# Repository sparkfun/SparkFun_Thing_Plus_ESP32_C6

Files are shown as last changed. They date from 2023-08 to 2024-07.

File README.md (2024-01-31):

SparkFun Thing Plus - ESP32-C6
==============================

SparkFun Thing Plus - ESP32-C6 (https://www.sparkfun.com/products/22924)

[*SparkFun Thing Plus - ESP32-C6 (DEV-22924)*](https://www.sparkfun.com/products/22924)

The SparkFun Thing Plus ESP32-C6 is a powerful wireless development board built around the ESP32-C6 WROOM-1-N16 wireless module from espressif<sup>&trade;</sup>. The ESP32-C6 is built around a single-core RISC-V processor with 16MB internal Flash memory. It supports WiFi 6, Bluetooth<sup>&reg;</sup> 5.3, Zigbee and Thread (802.12.4) wireless protocols and has a built-in PCB antenna. The ESP32-C6 has 23 multifunctional GPIO (*most* peripherals available on any GPIO), up to 7 12-bit ADC channels, up to 2 UARTs, USB Serial, one Low-Power UART, two I<sup>2</sup>C buses (one standard, one low-power), and one I<sup>2</sup>S bus.

This Thing Plus has a pair of 0.1"-spaced plated through hole (PTH) pins breaking out all of the ESP32's GPIO pins as well as connections for Reset, Boot, regulator enable, and the voltage rails (3.3V, USB, Battery), a USB-C connector, 2-pin JST connector for attaching a single-cell LiPo battery, MCP73831 battery charger, MAX17048 battery fuel gauge, 4-pin Qwiic connector, and &micro;SD card slot. The board has three LEDs for Power (Red), Battery Charge Indicator (Yellow), and STAT (RGB WS2812). The WS2812's data-in pin is tied to IO23 on the ESP32-C6.  

Repository Contents
-------------------

* **/Documents** - Datasheets, additional product information 
* **/Hardware** - Eagle design files (.brd, .sch)
* **/Production** - Production panel files (.brd)
* **/docs** - Documentation files for the Thing Plus ESP32-C6

Documentation
--------------

* **[Hookup Guide](https://docs.sparkfun.com/SparkFun_LTE_Stick_LARA_R6)** - Basic hookup guide for the SparkFun Thing Plus - ESP32-C6.

Product Versions
----------------
* [DEV-22924](https://www.sparkfun.com/products/22924) - Initial release

License Information
-------------------

This product is _**open source**_! 

Please review the LICENSE.md file for license information. 

If you have any questions or concerns on licensing, please contact technical support on our [SparkFun forums](https://forum.sparkfun.com/viewforum.php?f=152).

Distributed as-is; no warranty is given.

- Your friends at SparkFun.

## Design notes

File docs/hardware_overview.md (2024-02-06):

---
icon: material/cog
---

Let's take a closer look at the ESP32-C6 WROOM1 module and other hardware present on this Thing Plus board.

## ESP32-C6 WROOM1 Module

The ESP32-C6 WROOM1 module from espressif combines a powerful RISC-5 processor with a wireless stack compatible with most common wireless protocols.

<figure markdown>
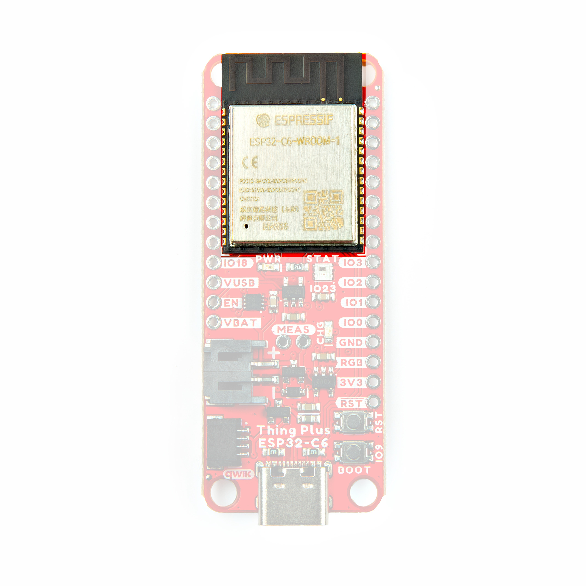
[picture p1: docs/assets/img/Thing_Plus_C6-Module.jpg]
Photo highlighting ESP32-C6 module.

</figure>

This development board uses the WROOM1 version of the C6 module which has slightly more computing power in exchange for lesser power efficiency. The ESP32-C6 is built around a 32-bit RISC-V single-core processor with an integrated wireless stack. The wireless stack is compatible with 2.4 GHz WiFi 6, Bluetooth<sup>&reg;</sup> 5.3, Zigbee and Thread (802.15.4) and uses an on-board PCB antenna. 

The module features a wide range of peripheral options including SPI, UART, LPUART, I<sup>2</sup>C, I<sup>2</sup>S, LED PWM, USB Serial/JTAG controller, ADC and more. Many of these peripherals can be mapped to any GPIO pin though some are tied to specific pins. This Thing Plus breaks out 21 pins from the module to a pair of 0.1"-spaced PTH headers.

The ESP32-C6 has 16 MB Flash memory along with 512 KB SRAM (high power)/ 16 KB SRAM (low power). The module uses pin strapping to configure boot mode parameters. The board defaults to standard mode (GPIO 9 internal pull-up, all other strapping pins floating) but it can be set to other parameters by performing the following pin strapping:

* SDIO Sampling and Driving Clock Edge - MTMS & MTDI
* Chip Boot Mode - GPIO8 & GPIO9
* ROM Code Printing to UART - GPIO8
* JTAG Signal Source - GPIO15

## Power Components

The Thing Plus ESP32-C6 includes several options for powering including USB-C, LiPo battery with on-board battery charging and monitoring circuits as well as direct power inputs.

<figure markdown>
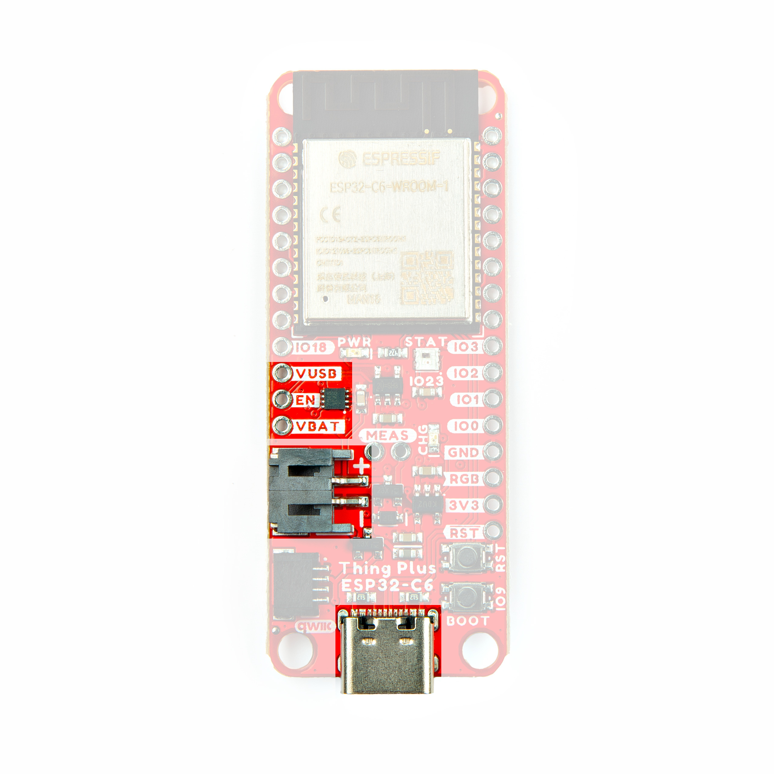
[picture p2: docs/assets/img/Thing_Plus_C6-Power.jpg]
Photo highlighting power components/pins.

</figure>

### USB-C Connector

The USB-C connector on the board acts as the primary serial interface for the ESP32-C6 module as well as a power input. It connects directly to the ESP32-C6's USB serial converter. The <b>5V</b> USB input voltage is regulated down to <b>3.3V</b> through a voltage regulator with a max current of <b>500mA@3.3V</b>.

### 2-Pin JST Connector, Battery Charger, & Fuel Gauge

The board has a 2-pin JST connector to connect a single-cell Lithium Ion (LiPo) battery for battery-powered applications. It also has an MCP73831 battery charger to charge an attached battery and a MAX17048 fuel gauge to monitor battery voltage levels over I<sup>2</sup>C. The charge rate is set to <b>214mA@3.3V</b>. The MCP73831 receives power from the V_USB line so it only is powered when <b>5V</b> is provided either over USB or the V_USB PTH pin. If applying voltage directly to the V_USB pin make sure it does not exceed <b>5.5V</b>.

## Pinout & Qwiic Connector

Next up let's take a look at the Thing Plus pinout and Qwiic connector on this board.

<figure markdown>
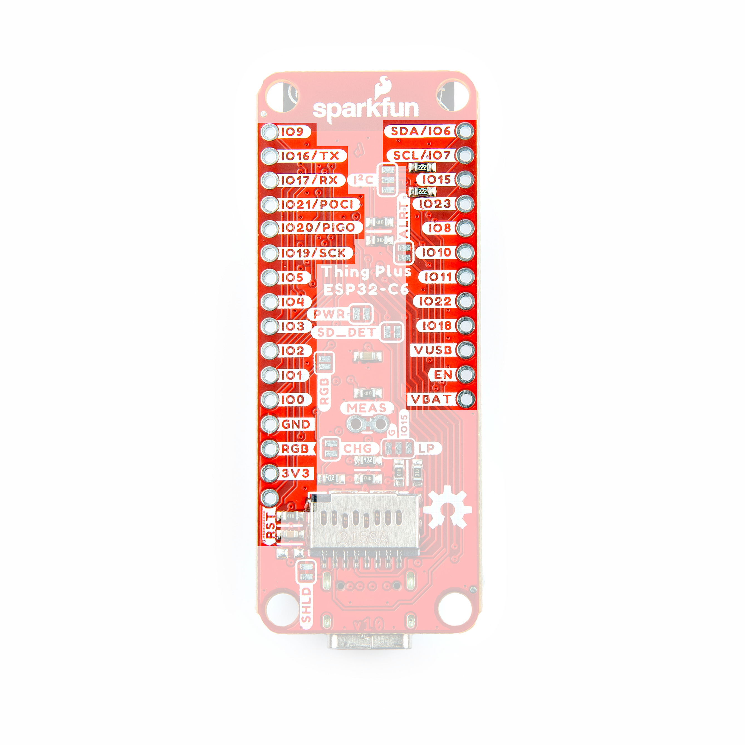
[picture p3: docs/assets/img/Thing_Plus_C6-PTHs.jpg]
Photo highlighting through-hole pinouts.

</figure>

### PTH Headers

The Thing Plus routes 23 of the ESP32-C6's GPIO pins to a pair of 0.1"-spaced headers on either side of the board. This includes all seven of the 12-bit ADC-capable pins, one UART, one I<sup>2</sup>C bus (SDA/SCL), one SPI interface (POCI/PICO/SCK), and seven GPIO pins. Some of the GPIO connect to specific functions on the board by default through solder jumpers listed below:

* IO18 - CS
* IO22 - SD Detect
* IO11 - MAX17038 Alert
* IO23 - WS2812 STAT LED Data In
* IO15 - Low Power control

### Qwiic Connector

There's a Qwiic connector on the board tied to the ESP32-C6's Low Power I<sup>2</sup>C bus (I/O pins 6 and 7) for easy integration into SparkFun's Qwiic ecosystem. The Qwiic connector provides connections for SDA, SCL, 3.3V, and Ground.

## Buttons

There are two buttons on the board labeled <b>RESET</b> and <b>BOOT</b>. The RESET button is tied to the ESP32-C6's Enable (EN) pin and resets the module when pressed. The BOOT button puts the ESP32-C6 into bootloader mode when held down during power on or reset.

<figure markdown>
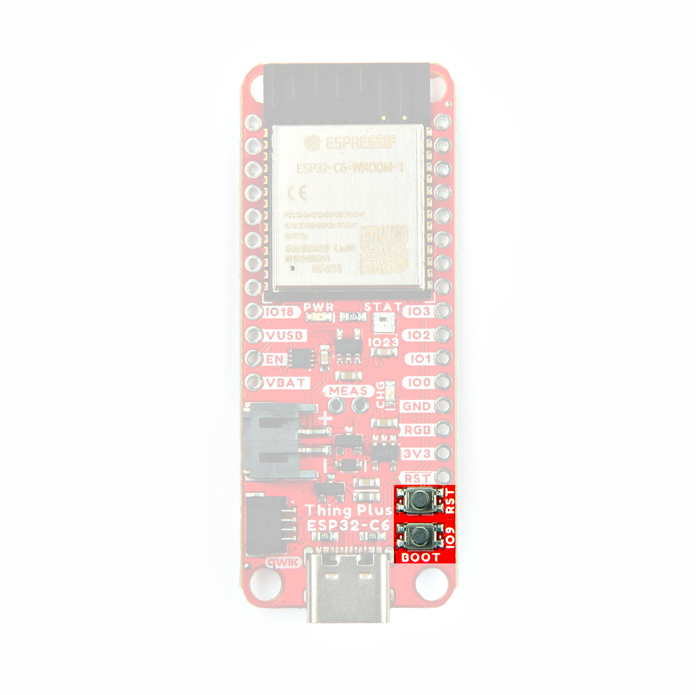
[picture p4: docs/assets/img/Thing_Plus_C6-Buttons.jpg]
Photo highlighting buttons.

</figure>

## &micro;SD Card Slot

This board also has a friction-fit &micro;SD card slot for users who need more storage space on the Thing Plus - ESP32-C6. 

<figure markdown>
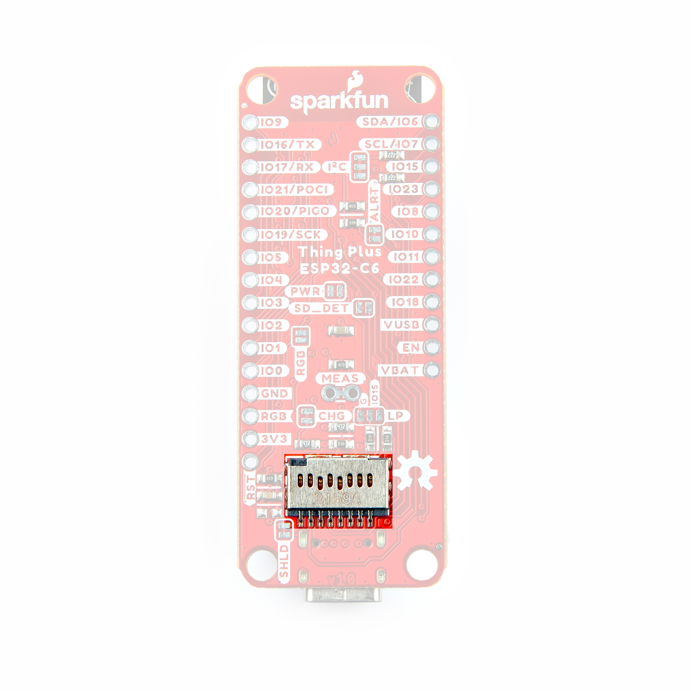
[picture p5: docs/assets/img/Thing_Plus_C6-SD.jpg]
Photo highlighting microSD card slot

</figure>

The slot connects the SD card's communication interface to the ESP32-C6's SPI interface using the following pins:

* SD Serial Data Out: IO21/POCI
* SD Serial Data In: IO20/PICO
* SD Serial Clock: IO19/SCK
* SD Chip Select: IO18/CS
* SD Detect: IO22/SD_DET

## LEDs

This Thing Plus has three LEDs labeled <b>PWR</b>, <b>CHG</b>, and <b>STAT</b>. The red Power (PWR) LED indicates whenever the <b>3.3V</b> circuit is powered. The yellow Charge (CHG) LED indicates whenever the MCP73831 is charging a connected LiPo battery. The WS2812 RGB Status (STAT) LED connects the LED's Data In signal to IO23.

<figure markdown>
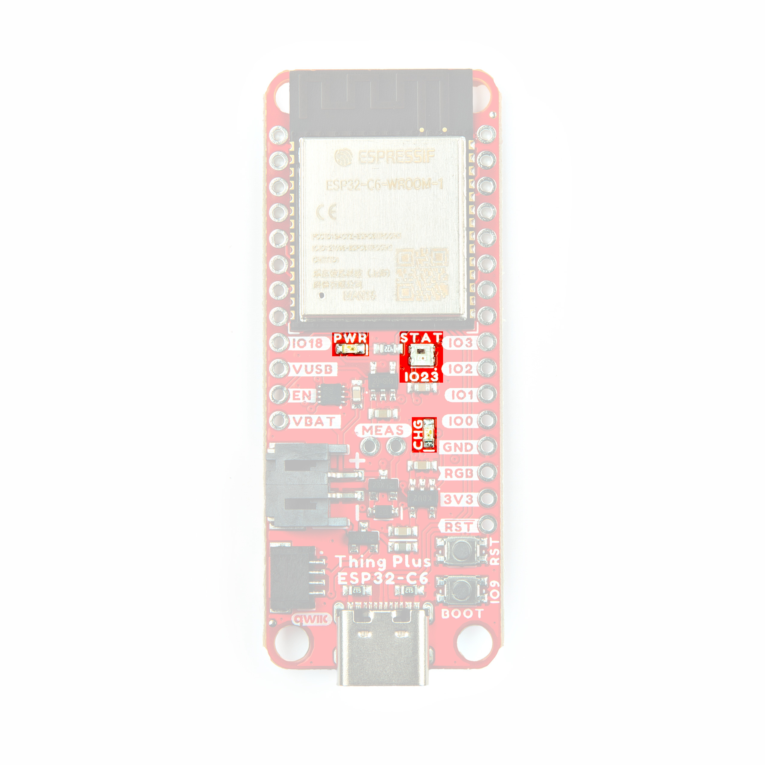
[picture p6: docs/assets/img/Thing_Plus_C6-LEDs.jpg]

</figure>

!!! note "RGB LED"
    The board definition for the Thing Plus - ESP32-C6 sets IO23 to use espressif's `RGB_BUILTIN` code support. This automatically includes the necessary code to control an RGB LED easily when calling `RGB_BUILTIN`. Unfortunately, this means the RGB PTH pin (IO23) can run into code conflicts when users attempt to use it for another purpose. If you *really* need IO23 for something other than the RGB LED, you may need to modify the board definition files in the ESP32 Arduino boards package. Modifying these files is beyond the scope of this tutorial and is not supported by SparkFun.

## Solder Jumpers

There are nine solder jumpers on the Thing Plus - ESP32-C6 labeled <b>I<sup>2</sup>C</b>, <b>ALRT</b>, <b>SD_DET</b>, <b>MEAS</b>, <b>LP</b>, <b>SHLD</b>, <b>RGB</b>, <b>CHG</b>, and <b>PWR</b>. The table below outlines the jumpers' labels, default state, function, and any notes regarding their use:

<figure markdown>
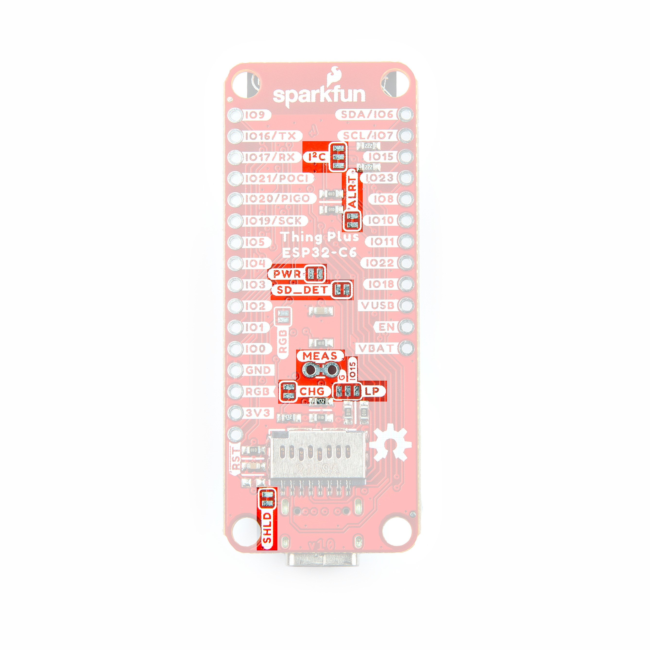
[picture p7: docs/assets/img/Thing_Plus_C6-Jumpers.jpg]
Photo highlighting solder jumpers.

</figure>

<table>
    <tr>
        <th>Label</th>
        <th>Default State</th>
        <th>Function</th>
        <th>Notes</th>
    </tr>
    <tr>
        <td>I<sup>2</sup>C</td>
        <td>CLOSED</td>
        <td>Three-way jumper pulls the SDA/SCL lines to <b>3.3V</b> through a pair of <b>2.2k&ohm;</b> resistors</td>
        <td>Open completely to disable pullups on I<sup>2</sup>C bus if needed</td>
    </tr>
    <tr>
        <td>ALRT</td>
        <td>CLOSED</td>
        <td>Ties the MAX17048's alert pin to IO11 for battery voltage monitoring</td>
        <td>Open to isolate IO11 from the MAX17048's alert pin if IO11 is needed for other uses</td>
    <tr>
        <td>SD_DET</td>
        <td>CLOSED</td>
        <td>Connects the &micro;SD card's card detection pin to IO19</td>
        <td>Open to disable &micro;SD card detection or if IO19 is needed for other uses</td>
    </tr>
    <tr>
        <td>MEAS</td>
        <td>CLOSED</td>
        <td>Completes the input voltage circuit from V_USB & V_Batt to the 3.3V regulator</td>
        <td>Open to interrupt the circuit to measure current consumed by the board with a <a href="https://learn.sparkfun.com/tutorials/how-to-use-a-multimeter#measuring-current">digital multimeter</a></td>
    </tr>
    <tr>
        <td>LP</td>
        <td>See Note</td>
        <td>Enables/disables low power control for the ESP32-C6</td>
        <td>Three-way jumper. Defaults to disabled (connects to Ground). Adjust to IO15 side to enable low power control</td>
    </tr>
    <tr>
        <td>SHLD</td>
        <td>CLOSED</td>
        <td>Ties the USB-C shield pin to the ground plane</td>
        <td>Open to isolate USB-C shield pin from the board's ground plane</td>
    </tr>
    <tr>
        <td>RGB</td>
        <td>Open</td>
        <td>Connects WS2812 data out (DO) signal to the No Connect/AREF PTH pin</td>
        <td>Open to isolate DO signal from the No Connect/AREF PTH pin to chain with other WS2812 LEDs</td>
    </tr>
    <tr>
        <td>CHG</td>
        <td>CLOSED</td>
        <td>Completes Charge LED circuit</td>
        <td>Open to disable Charge LED</td>
    </tr>
    <tr>
        <td>PWR</td>
        <td>CLOSED</td>
        <td>Completes the Power LED circuit</td>
        <td>Open to disable the Power LED</td>
    </tr>
</table>

## Board Dimensions

This board matches the Thing Plus footprint and measures 2.30" x 0.90" (58.42mm x 22.86mm) with four mounting holes that fit a [4-40 screw](https://www.sparkfun.com/products/10453) though the top two mounting holes are obstructed by the ESP32-C6 module.

<figure markdown>
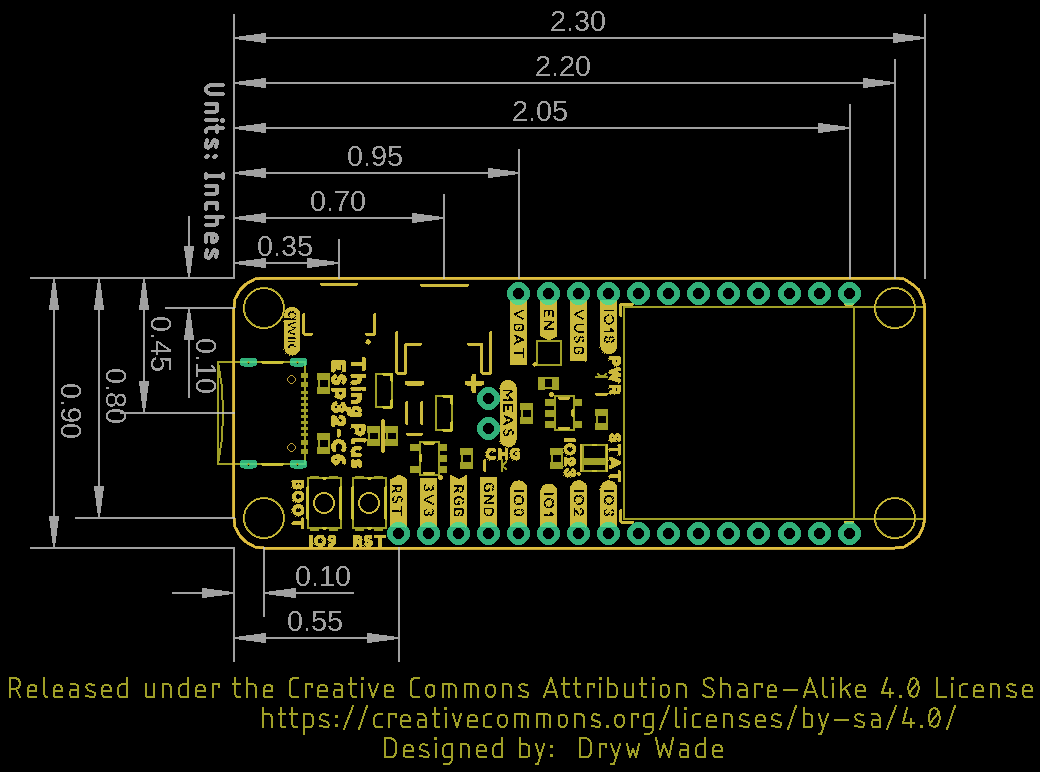
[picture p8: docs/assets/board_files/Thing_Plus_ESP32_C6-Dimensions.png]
Board dimensions.

</figure>

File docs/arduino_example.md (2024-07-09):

---
icon: simple/arduino
---

Now that we've installed the espressif boards package in Arduino, it's time to upload our first sketch to make sure everything is working properly.

## Blink RGB Example

The ESP32 core includes integrated code support for easily controlling a WS2812 LED and an example demonstrating how to cycle an RGB LED like the one found on this Thing Plus so long as the board variant defines it as `RGB_BUILTIN`. The Thing Plus ESP32-C6 does define IO23 as `RBG_BUILTIN` so this example and all other code calling for the built-in RGB LED works for this board. Open the example by navigating to **File** > **Examples** > **ESP32** > **GPIO** > **BlinkRGB** like the screenshot below shows: 

<figure markdown>
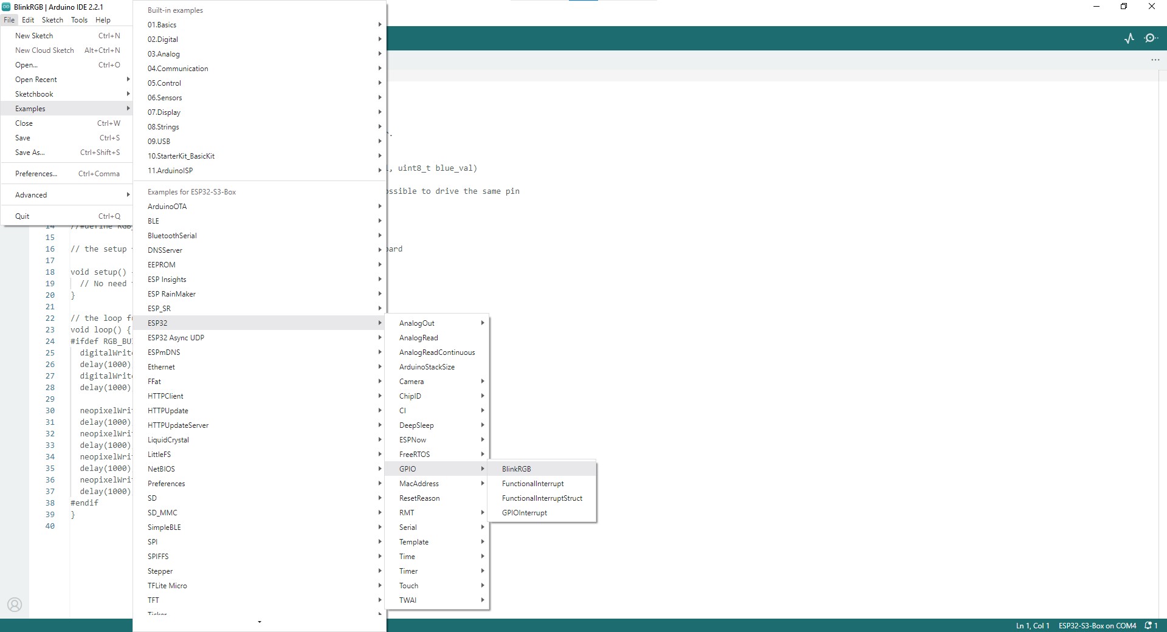
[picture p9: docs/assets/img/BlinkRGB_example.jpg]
Screenshot of selecing the Blink RGB example.

</figure>

Select the board (SparkFun Thing Plus - C6) and Port and click "Upload". After uploading you should see the STAT LED on the board turn on full white, turn off, and then cycle through red, green, and blue repeatedly.

!!! note "USB CDC On Boot Settings"

    Take note of the option labeled "USB CDC on Boot" when selecting the Board from the Tools menu. This option sets the serial outputs and defines their label for use in code. The SparkFun variants default to Enable USB CDC on boot which sets both <code>Serial</code> and <code>Serial0</code> as available serial ports. In this configuration, <code>Serial</code> corresponds to the direct USB/Serial converter on the chip (and the USB-C interface) and <code>Serial0</code> corresponds to the UART0 bus (default pins are 16 and 17).

    With either setting, <code>Serial1</code> is available and refers to the UART1 bus (default pins are 4 and 5).

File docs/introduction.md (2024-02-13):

---
icon: material/book-open-page-variant
---

<div class="grid cards desc" markdown>

-    <a href="https://www.sparkfun.com/products/22924">
    **SparkFun Thing Plus - ESP32-C6**<br>
    **SKU:** DEV-22924

    ---

    <figure markdown>
    Product Thumbnail
    </figure></a>

    <center>
    <article class="video_desc">
    <iframe src=" https://www.youtube.com/embed/UqpQe8Y62ho" title="Product Showcase: SparkFun LTE Stick - LARA-R6" frameborder="0" allow="accelerometer; autoplay; clipboard-write;encrypted-media; gyroscope; picture-in-picture" allowfullscreen></iframe>
    </article>
    </center>

-    The SparkFun Thing Plus - ESP32-C6 adds a powerful wireless development option to SparkFun's popular Thing Plus footprint. This Thing Plus board features the ESP32-C6 WROOM-1-N16 module from espressif<sup>&trade;</sup>. It includes a LiPo battery charger and fuel gauge to charge and monitor a battery connected to the on-bard 2-pin JST connector, &microSD card slot, an addressable LED and more. The board breaks out all of the ESP32-C6's 23 GPIO pins to a pair of 0.1"-spaced PTH headers on either side of the board. The board also has a USB-C connector for primary power and programming and a Qwiic connector to integrate it into SparkFun's [Qwiic ecosystem](https://www.sparkfun.com/qwiic).

    The ESP32-C6 SoC is built around a RISC-V single-core processor with 16 MB flash memory with an integrated wireless stack. The wireless stack supports 2.4 GHz WiFi 6, Bluetooth<sup>&reg;</sup> 5.3, Zigbee and Thread (802.15.4) and uses an on-board PCB antenna. The ESP32-C6 includes a wide range of peripheral options including SPI, UART, LPUART, I<sup>2</sup>C, I<sup>2</sup>S, LED PWM, USB Serial/JTAG controller, ADC and more. Many of these peripherals can be mapped to any GPIO pin though some are tied to specific pins. 

    <center>
    [Purchase from SparkFun :fontawesome-solid-cart-plus:{ .heart }](https://www.sparkfun.com/products/22924){ .md-button .md-button--primary }
    </center>

</div>

## Required Materials

To follow along with this guide you will need at least one USB-C cable to connect the Thing Plus to your computer: 

<div class="grid cards" markdown>

-   <a href="https://www.sparkfun.com/products/14743">

    <figure markdown>
    USB 3.1 Cable A to C - 3 Foot
    </figure>
    </a>
    ---
    <a href="https://www.sparkfun.com/products/14743">
    **USB 3.1 Cable A to C - 3 Foot**<br>
    CAB-14743
    </a>

-   <a href="https://www.sparkfun.com/products/15424">
    
    <figure markdown>
    Reversible USB A to C Cable - 2m
    </figure>
    </a>
    ---
    <a href="https://www.sparkfun.com/products/15424">
    **Reversible USB A to C Cable - 2m**<br>
    CAB-15424
    </a>
</div>

You may also want to get a Qwiic cable or kit to connect the Thing Plus - ESP32-C6 to other Qwiic devices:

<div class="grid cards" markdown>

-   <a href="https://www.sparkfun.com/products/17260">
    
    <figure markdown>
    Qwiic Cable - 50mm
    </figure>
    </a>
    ---
    <a href="https://www.sparkfun.com/products/17260">
    **Flexible Qwiic Cable - 50mm**<br>
    PRT-17260
    </a>

-   <a href="https://www.sparkfun.com/products/17257">
    
    <figure markdown>
    Flexible Qwiic Cable - 500mm
    </figure>
    </a>
    ---
    <a href="https://www.sparkfun.com/products/17257">
    **Flexible Qwiic Cable - 500mm**<br>
    PRT-17257
    </a>

-   <a href="https://www.sparkfun.com/products/17261">

    <figure markdown>
    Flexible Qwiic Cable - Female Jumper (4-pin)
    </figure>
    </a>
    ---
    <a href="https://www.sparkfun.com/products/17261">**Flexible Qwiic Cable - Female Jumper (4-pin)**<br>
    CAB-17261
    </a>

-   <a href="https://www.sparkfun.com/products/15081">

    <figure markdown>
    SparkFun Qwiic Cable Kit
    </figure>
    </a>
    ---
    <a href="https://www.sparkfun.com/products/15081">
    **SparkFun Qwiic Cable Kit**<br>
    PRT-15081
    </a>

</div>

## Optional Materials

The Thing Plus - ESP32-C6 includes a 2-pin JST connector and integrated charging circuit for an attached single-cell LiPo battery. Below are a few options we recommend for battery-powered applications:

<div class="grid cards" markdown align="center">

-   <a href="https://www.sparkfun.com/products/18286">

    <figure markdown>
    Lithium Ion Battery - 1250mAh (IEC62133 Certified)
    </figure>
    </a>
    ---
    <a href="https://www.sparkfun.com/products/18286">
    **Lithium Ion Battery - 1250mAh (IEC62133 Certified)**<br>
    PRT-18286
    </a>

-   <a href="https://www.sparkfun.com/products/13855">

    <figure markdown>
    Lithium Ion Battery - 2Ah
    </figure>
    </a>
    ---
    <a href="https://www.sparkfun.com/products/13855">
    **Lithium Ion Battery - 2Ah**<br>
    PRT-13855
    </a>

-   <a href="https://www.sparkfun.com/products/13851">

    <figure markdown>
    Lithium Ion Battery - 400mAh
    </figure>
    </a>
    ---
    <a href="https://www.sparkfun.com/products/13851">
    **Lithium Ion Battery - 400mAh**<br>
    PRT-13851
    </a>

-   <a href="https://www.sparkfun.com/products/13854">

    <figure markdown>
    Lithium Ion Battery - 850mAh
    </figure>
    </a>
    ---
    <a href="https://www.sparkfun.com/products/13854">
    **Lithium Ion Battery - 850mAh**<br>
    PRT-13854
    </a>
</div>

If you prefer a soldered connection or want to modify the solder jumpers on this board, you may need some of the products listed below:

<div class="grid cards" markdown align="center">

-   <a href="https://www.sparkfun.com/products/116">

    <figure markdown>
    SparkFun Qwiic Shield for Thing Plus
    </figure>
    </a>
    ---
    <a href="https://www.sparkfun.com/products/16790">
    **SparkFun Qwiic Shield for Thing Plus**<br>
    DEV-16790
    </a>

-   <a href="https://www.sparkfun.com/products/9507">
    
    <figure markdown>
    PINECIL - Smart Mini Portable Soldering Iron
    </figure>
    </a>
    ---
    <a href="https://www.sparkfun.com/products/23913">
    **PINECIL - Smart Mini Portable Soldering Iron**<br>
    TOL-23913
    </a>

-   <a href="https://www.sparkfun.com/products/9200">
    
    <figure markdown>
    Hobby Knife
    </figure>
    </a>
    ---
    <a href="https://www.sparkfun.com/products/9200">
    **Hobby Knife**<br>
    TOL-09200
    </a>

-   <a href="https://www.sparkfun.com/products/14579">

    <figure markdown>
    Chip Quik No-Clean Flux Pen - 10mL
    </figure>
    </a>
    ---
    <a href="https://www.sparkfun.com/products/14579">**Chip Quik No-Clean Flux Pen - 10mL**<br>
    CAB-14579
    </a>
</div>

## Suggested Reading

We designed this board for integration into SparkFun's Qwiic connect system.  Click on the banner below to learn more about the [SparkFun Qwiic Connect System](https://www.sparkfun.com/qwiic).

<div style="text-align: center">
<table>
  <tr>
   <td>
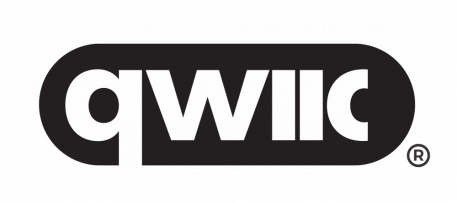
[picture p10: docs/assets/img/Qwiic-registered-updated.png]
Qwiic Connect System Click to learn more about the Qwiic Connect System!
   <div style="text-align: center"></div>
   </td>
  </tr>
  <tr>
    <td><div style="text-align: center"><i><a href="https://www.sparkfun.com/qwiic">Qwiic Connect System</a></i></div></td>
  </tr>
</table>
</div>

Before getting started with this Hookup Guide, you may want to read through the tutorials below if you are not familiar with the concepts covered in them or want a refresher. If you are using either of the Qwiic Shields linked above, we recommend reading through their respective Hookup Guides before continuing with this tutorial:

<div class="grid cards hide col-4" markdown align="center">

-   <a href="https://learn.sparkfun.com/tutorials/8">
    <figure markdown>
    Serial Communication
    </figure>
    </a>
    <a href="https://learn.sparkfun.com/tutorials/8">**Serial Communication**
    </a>

-   <a href="https://learn.sparkfun.com/tutorials/82">
    <figure markdown>
    I2C
    </figure>
    </a>
    <a href="https://learn.sparkfun.com/tutorials/82">**I2C**
    </a>

-   <a href="https://learn.sparkfun.com/tutorials/62">
    <figure markdown>
    Logic Levels
    </figure>
    </a>
    <a href="https://learn.sparkfun.com/tutorials/62">**Logic Levels**
    </a>

-   <a href="https://learn.sparkfun.com/tutorials/61">
    <figure markdown>
    Installing Arduino IDE
    </figure>
    </a>
    <a href="https://learn.sparkfun.com/tutorials/61">**Installing Arduino IDE**
    </a>

-   <a href="https://learn.sparkfun.com/tutorials/15">
    <figure markdown>
    Installing an Arduino Library
    </figure>
    </a>
    <a href="https://learn.sparkfun.com/tutorials/15">**Installing an Arduino Library**
    </a>

-   <a href="https://learn.sparkfun.com/tutorials/112">
    <figure markdown>
    Serial Terminal Basics
    </figure>
    </a>
    <a href="https://learn.sparkfun.com/tutorials/112">**Serial Terminal Basics**
    </a>

-   <a href="https://learn.sparkfun.com/tutorials/1107">
    <figure markdown>
    SparkFun Qwiic Shield for Thing Plus Hookup Guide
    </figure>
    </a>
    <a href="https://learn.sparkfun.com/tutorials/1107">**SparkFun Qwiic Shield for Thing Plus Hookup Guide**
    </a>

-   <a href="https://learn.sparkfun.com/tutorials/664">
    <figure markdown>
    How to Work with Jumper Pads and PCB Traces
    </figure>
    </a>
    <a href="https://learn.sparkfun.com/tutorials/664">**How to Work with Jumper Pads and PCB Traces**
    </a>
</div>

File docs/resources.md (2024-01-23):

For more information on the Thing Plus ESP32-C6, check out the resources below:

* [Schematic](./assets/board_files/Thing_Plus_ESP32_C6.pdf)
* [Eagle Files](./assets/board_files/Thing_Plus_ESP32_C6.zip)
* [Board Dimensions](./assets/board_files/Thing_Plus_ESP32_C6-Dimensions.png)
* [Datasheet](./assets/component_documentation/ESP32-C6-WROOM-1-Datasheet.pdf) (ESP32-C6 WROOM-1)
* [Technical Reference Manual](./assets/component_documentation/ESP32-C6_Technical_Reference_Manual.pdf)
* [GitHub Repository](https://github.com/sparkfun/SparkFun_Thing_Plus_ESP32_C6)
* [Thing Plus Info Page](https://www.sparkfun.com/thing_plus)
* [Qwiic Info Page](https://www.sparkfun.com/qwiic)

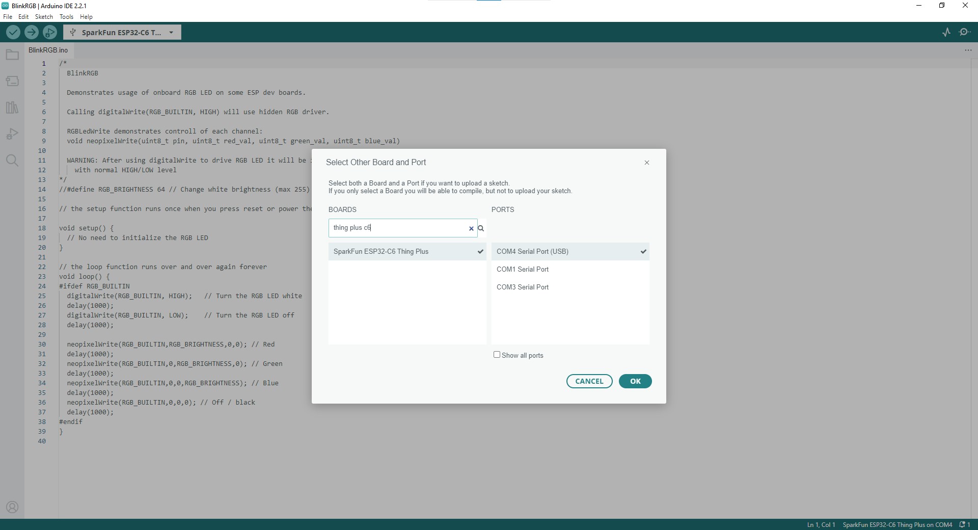
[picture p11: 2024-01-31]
docs/assets/img/Board_Selection.jpg

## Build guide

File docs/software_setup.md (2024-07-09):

---
icon: simple/arduino
---

!!! attention
	If this is your first time using Arduino, please read through our tutorial on [installing the Arduino IDE](https://learn.sparkfun.com/tutorials/installing-arduino-ide). If you have not installed an Arduino library before, we recommend you check out our [installation guide](https://learn.sparkfun.com/tutorials/installing-an-arduino-library).

With the ESP32-C6 Thing Plus connected to our computer, it's time to set up the boards package in Arduino.

## Installing espressif Arduino Boards
    
To install the ESP32 boards package, open the Preferences menu by navigating to <b>File</b> > <b>Preferences</b>. Look at the bottom of the Preferences menu for "Additional boards manager URLS" and then copy this JSON link into that field:

<code>
    https://espressif.github.io/arduino-esp32/package_esp32_dev_index.json
</code>

Click "Ok" and then open the *Boards Manager* tool, search for "espressif ESP32" and install the latest release. This install process may take some time so feel free to step away while it downloads and installs.

<figure markdown>
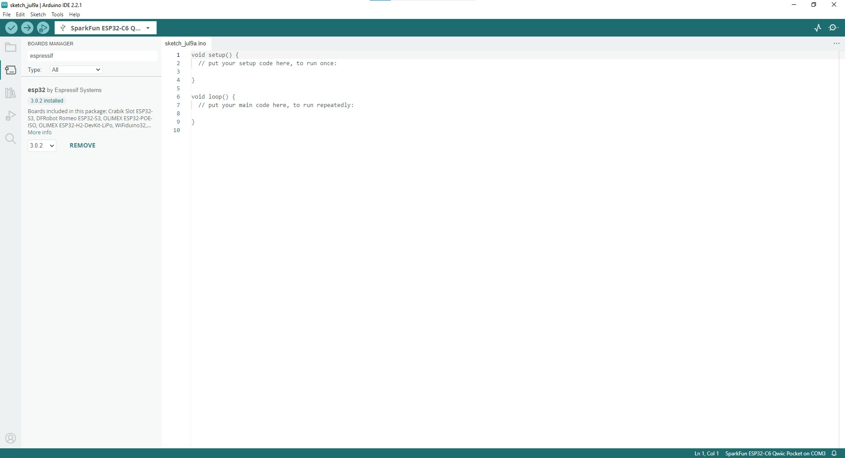
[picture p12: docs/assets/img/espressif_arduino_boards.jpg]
ESP32 Boards manager install.

</figure>

## espressif IDF

Users who prefer to use espressif's development toolkit, espressif IDF, can get started by following their instructions [here](https://www.espressif.com/en/products/sdks/esp-idf) and  ESP32-C6 specific documentation [here](https://docs.espressif.com/projects/esp-idf/en/stable/esp32c6/index.html).

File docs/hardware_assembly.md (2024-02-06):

---
icon: material/cog
---

Now that we're familiar with the hardware on this Thing Plus board, it's time to connect it to our computer or battery power.

## Basic USB Assembly

Basic assembly of the Thing Plus ESP32-C only requires a USB-C cable connecting the board to a computer. Just plug the cable into the USB-C connector like the photo below shows and you should see the RGB LED cycling through rainbow colors with the pre-loaded test code. From here, we can move on to installing the espressif boards package in Arduino and uploading code.

<figure markdown>
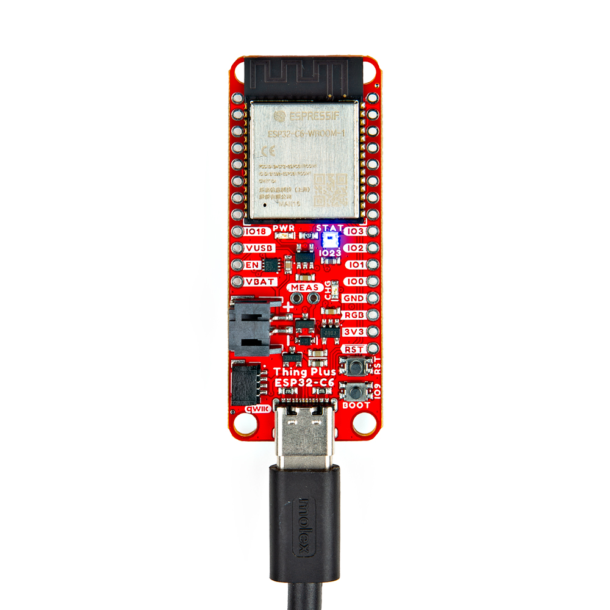
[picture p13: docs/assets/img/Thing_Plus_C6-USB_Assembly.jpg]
Photo of simple USB assembly.
    
</figure>

!!! note
    Your computer may not recognize the board as a known USB device if you have not installed the espressif boards package in Arduino and/or installed the espressif IDF.

## Battery Assembly

If you prefer a battery-powered application, plug a single-cell LiPo battery into the 2-pin JST connector on the underside of the board like the photo below. Remember, the MCP73831 only charges the battery when V_USB has voltage present either from the USB-C connector or through the V_USB PTH pin.

<figure markdown>
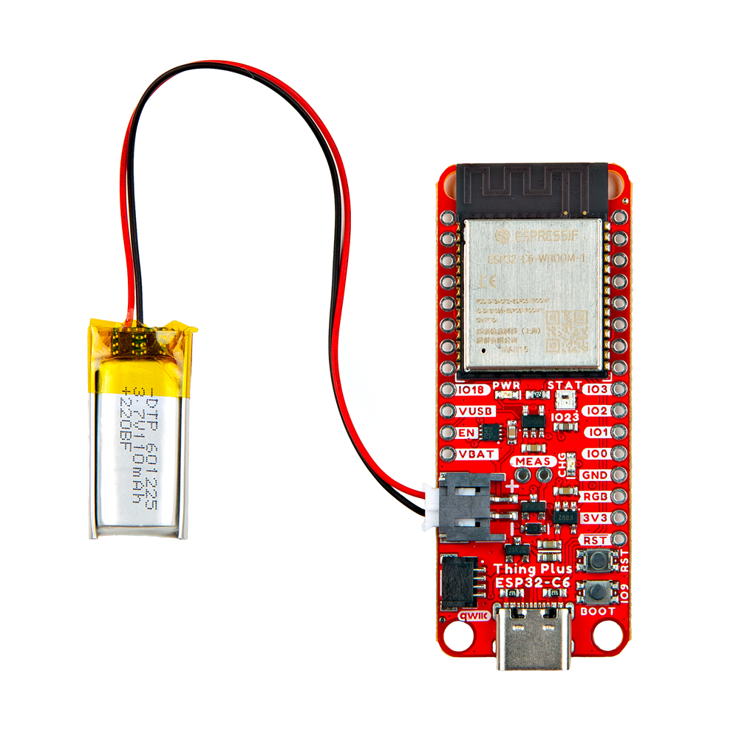
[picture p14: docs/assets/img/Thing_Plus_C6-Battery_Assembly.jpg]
Photo of battery assembly.

</figure>

For tips on the proper use of a LiPo battery and the 2-pin JST connector, please read through our [Single Cell LiPo Battery Care](https://learn.sparkfun.com/tutorials/single-cell-lipo-battery-care) tutorial.

## Soldered Assembly

Those who prefer a traditional soldered assembly should solder wires or header pins to the PTH header on the side of the board. If you're not familiar with through-hole soldering or would like a refresher, take a look at our Through-Hole Soldering Tutorial:

<div class="grid cards" markdown align="center">

-   <a href="https://learn.sparkfun.com/tutorials/5">
    <figure markdown>
    How to Solder: Through-Hole Soldering
    </figure>
    </a>
    <a href="https://learn.sparkfun.com/tutorials/5">**How to Solder: Through-Hole Soldering**
    </a>

</div>

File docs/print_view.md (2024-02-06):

---
hide:
  - navigation
  - toc
icon: fontawesome/solid/scroll
---

# Introduction
--8<-- "./docs/introduction.md:5"

# Hardware Overview
--8<-- "./docs/hardware_overview.md:5"

# Hardware Assembly
--8<-- "./docs/hardware_assembly.md:5"

## Software Setup
--8<-- "./docs/software_setup.md:5"

## Arduino Examples
--8<-- "./docs/arduino_example.md"

# Troubleshooting Tips
--8<-- "./docs/troubleshooting.md:5"

# Resources:
--8<-- "./docs/resources.md"

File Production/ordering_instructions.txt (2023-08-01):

panel size, 107x201mm
PCB thickness, 1.6mm
number of layers, 4
controlled impedance, JLC7628
soldermask color, Red
silkscreen color, White
oz copper, 1oz
finish, HASL lead free
stencils, top+bottom
pcs per panel, 12
min trace width, 0.1778mm / 0.0070in
min drill size, 0.3048mm / 0.0120in
filename to layer stackup 1/2/3/4: GTL, GL2, GL3, GBL

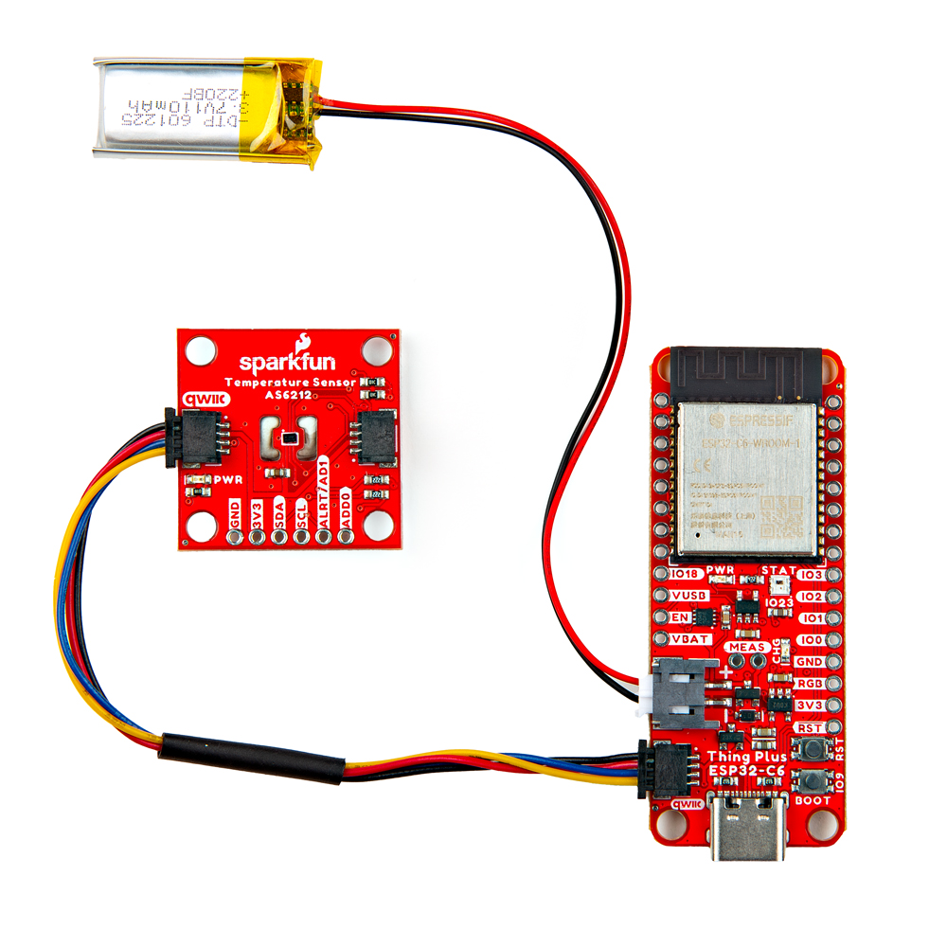
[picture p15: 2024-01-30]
docs/assets/img/Thing_Plus_C6-Qwiic_Batt_Assembly.jpg

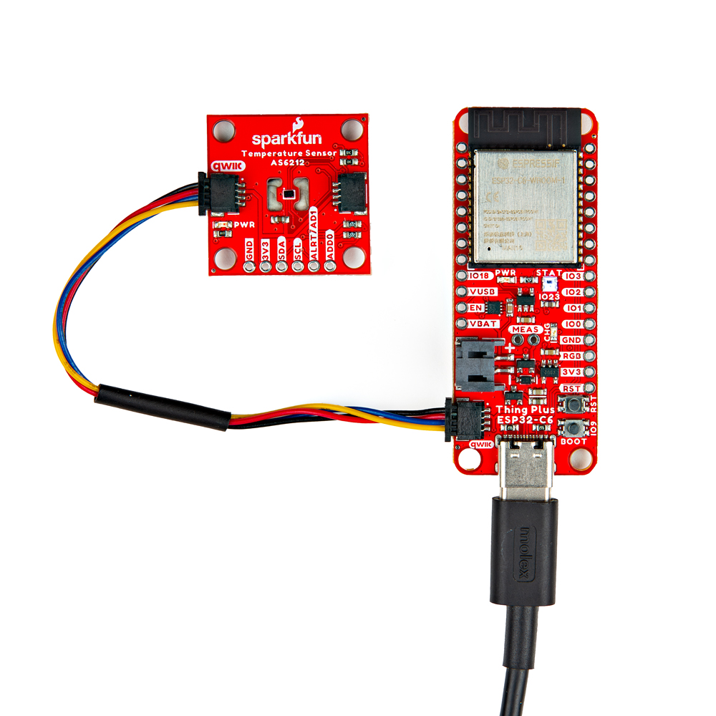
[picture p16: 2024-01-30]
docs/assets/img/Thing_Plus_C6-Qwiic_USB_Assembly.jpg

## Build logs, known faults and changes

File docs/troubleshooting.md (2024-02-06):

## USB CDC on Boot Settings

Take note of the option labeled "USB CDC on Boot" when selecting the Board from the Tools menu. This option sets the serial outputs and defines their label for use in code. The SparkFun variants default to Enable USB CDC on boot which sets both <code>Serial</code> and <code>Serial0</code> as available serial ports. In this configuration, <code>Serial</code> corresponds to the direct USB/Serial converter on the chip (and the USB-C interface) and <code>Serial0</code> corresponds to the UART0 bus (default pins are 16 and 17).

With either setting, <code>Serial1</code> is available and refers to the UART1 bus (default pins are 4 and 5).

## RGB LED Pin

The board definition for the Thing Plus - ESP32-C6 sets IO23 to use espressif's `RGB_BUILTIN` code support. This automatically includes the necessary code to control an RGB LED easily when calling `RGB_BUILTIN`. Unfortunately, this means the RGB PTH pin (IO23) can run into code conflicts when users attempt to use it for another purpose. If you *really* need IO23 for something other than the RGB LED, you may need to modify the board definition files in the ESP32 Arduino boards package. Modifying these files is beyond the scope of this tutorial and is not supported by SparkFun.

## General Troubleshooting

!!! warning "Need Help?"
    If you need technical assistance or more information on a product that is not working as you expected, we recommend heading on over to the [SparkFun Technical Assistance](https://www.sparkfun.com/technical_assistanc) page for some initial troubleshooting.

    <center>
    [SparkFun Technical Assistance Page](https://www.sparkfun.com/technical_assistance){ .md-button .md-button--primary }
    </center>
    
    If you can't find what you need there, the [SparkFun Forums](https://forum.sparkfun.com/index.php) is a great place to search product forums and ask questions.
    
    !!! info "Account Registration Required"
        If this is your first visit to our forum, you'll need to create a [Forum Account](https://forum.sparkfun.com/ucp.php?mode=register) to post questions.

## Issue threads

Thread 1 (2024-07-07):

Update docs to reflect Thing Plus ESP32-C6 board library availability

faludi, 2024-07-07:
The documentation in docs/software_setup.md should be updated to reflect that the Thing Plus ESP32-C6 is now included in the official ESP32 boards package, and that using the ESP32C6 Dev Module board definition is no longer required.

SFEMark, 2024-07-09:
The software_setup.md file and the relevant screenshots have been updated to the v3.x release of the ESP32 boards package.

Closed 2024-07-09.

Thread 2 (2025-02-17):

Fuel Gauge reporting voltage when no battery is connected

Topo-png, 2025-02-17:
I'm trying to troubleshoot a potential hardware issue.

When I power the ESP32-C6 Things Plus board via a usb cable (no battery connected- the Fuel Gauge reports back 4.0 +/- a 0.1V and provides a SOC.  Code is below

Based on the schematic it looks like the fuel gauge should only receive power when the battery is connected. When the battery and USB cable are connected, the SOC & Voltage do not change.

Could this be a potential mosfet failure, or is there another explanation?

using the following code

```
#include <Wire.h>
#include <SparkFun_MAX1704x_Fuel_Gauge_Arduino_Library.h>

SFE_MAX1704X lipo(MAX1704X_MAX17048);

void setup() {
  Serial.begin(115200);
  Wire.begin();

  if (!lipo.begin()) {
    Serial.println("MAX17048 not detected");
    while (1)
      ;
  }
  lipo.quickStart();
  lipo.setThreshold(20);
  digitalWrite(RGB_BUILTIN, HIGH);  // Turn the RGB LED white
}

void loop() {

  Serial.println(lipo.getVoltage());
  Serial.println(lipo.getSOC());
  delay(1000);
}
```

sfe-SparkFro, 2025-02-17:
Hi there,

This is expected behavior due to the presence of the battery charger. IIRC the charger IC attempts to detect a battery by supplying a small amount of current and watching how the voltage changes; if no battery is connected, the voltage rises quickly (to ~4V), and the charger determines no battery is connected, so it waits for a little while and repeats. The fuel gauge IC measures this voltage and determines a that battery is connected (and estimates a SoC). despite no battery actually being connected.

Sounds like there's no defect with your board, this behavior is just a side effect of having a charger on the board. Hope this helps!

Topo-png, 2025-02-17:
Thanks for the quick response. That makes sense.

Closed 2025-02-17.

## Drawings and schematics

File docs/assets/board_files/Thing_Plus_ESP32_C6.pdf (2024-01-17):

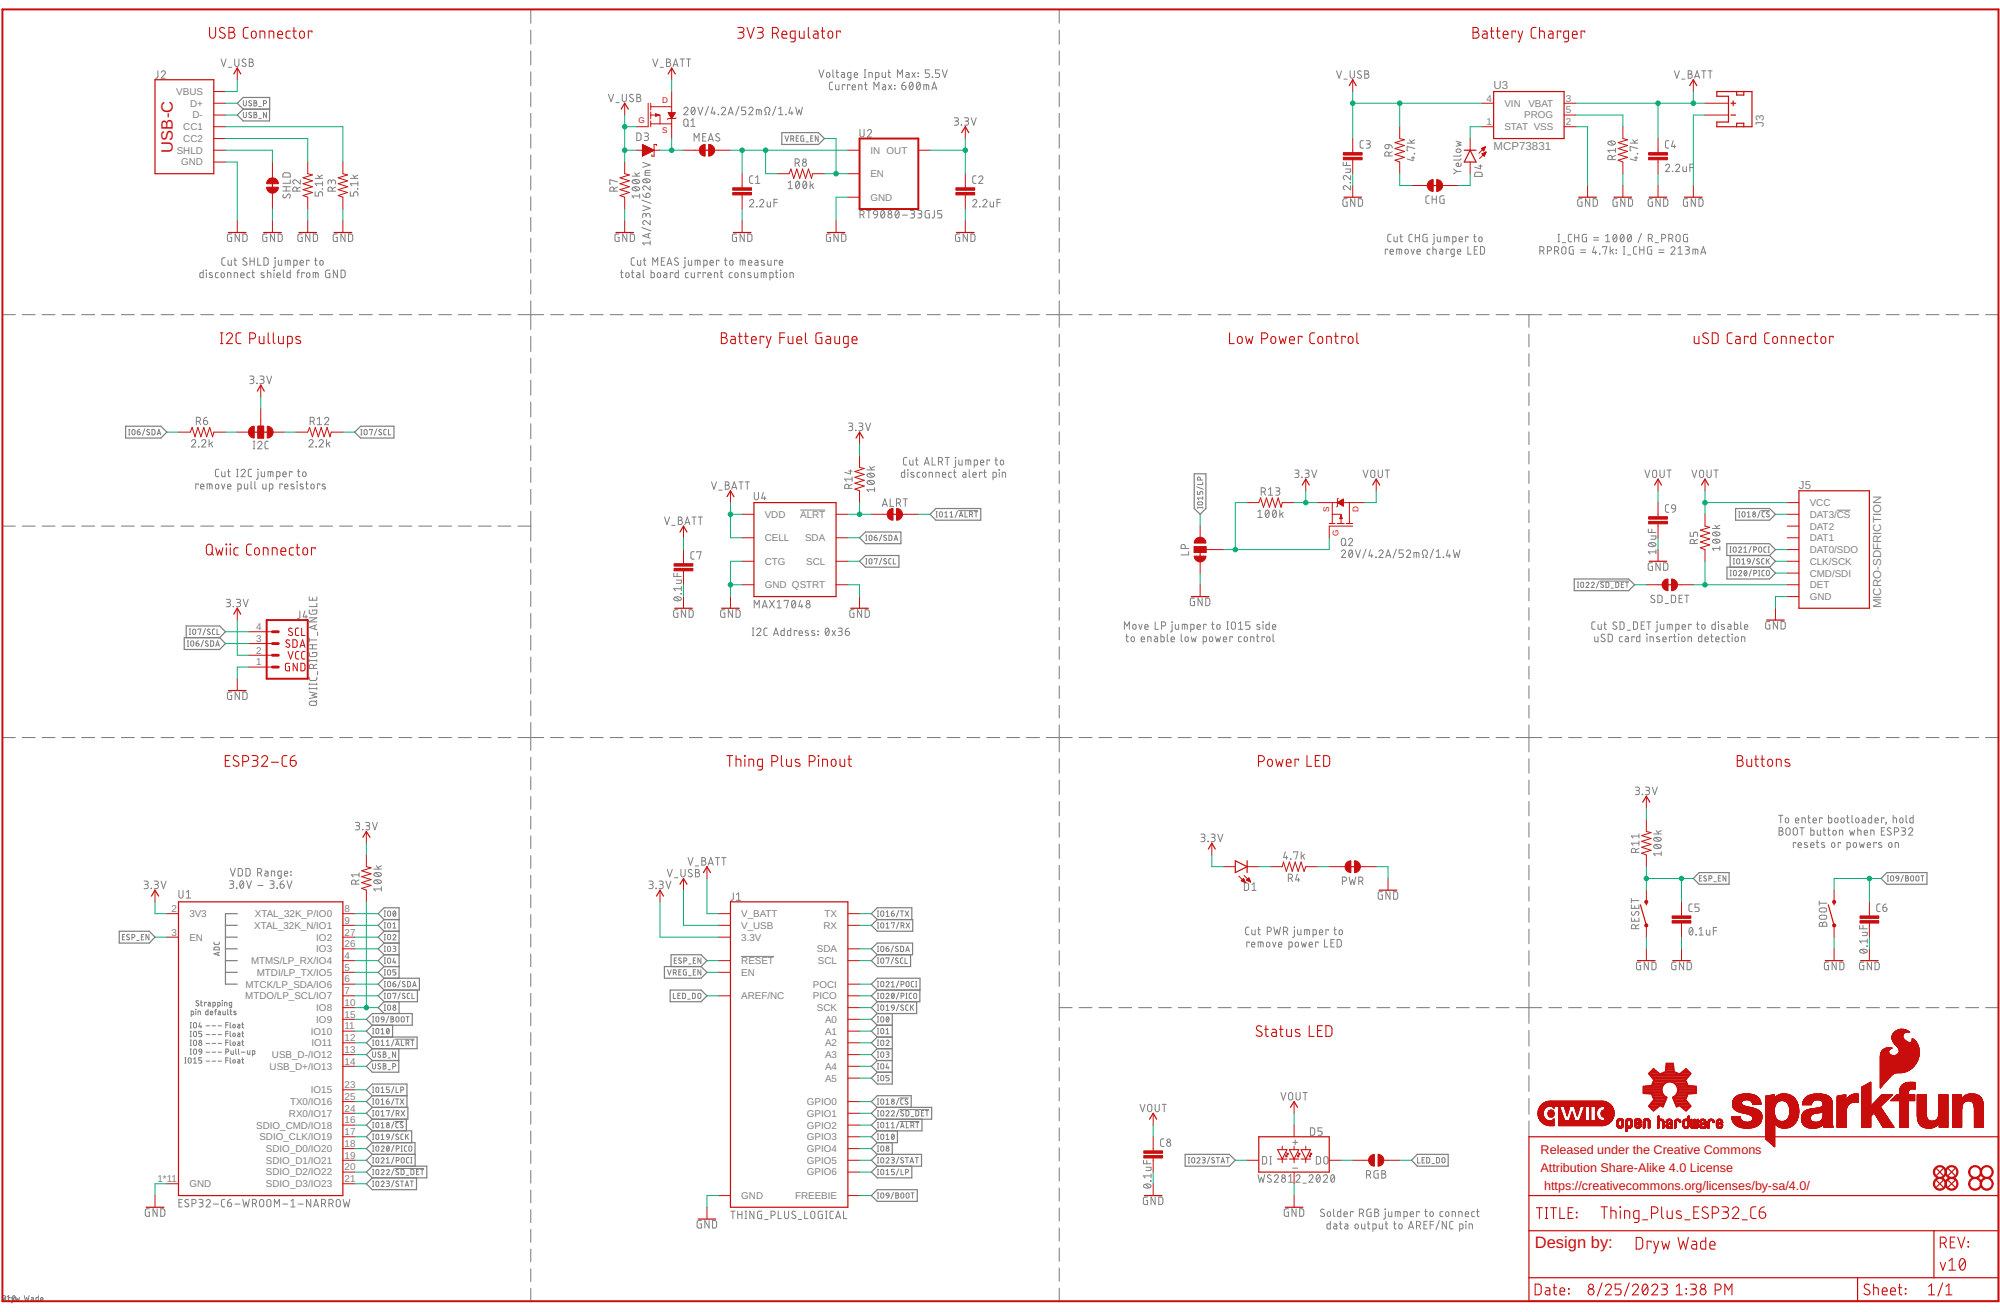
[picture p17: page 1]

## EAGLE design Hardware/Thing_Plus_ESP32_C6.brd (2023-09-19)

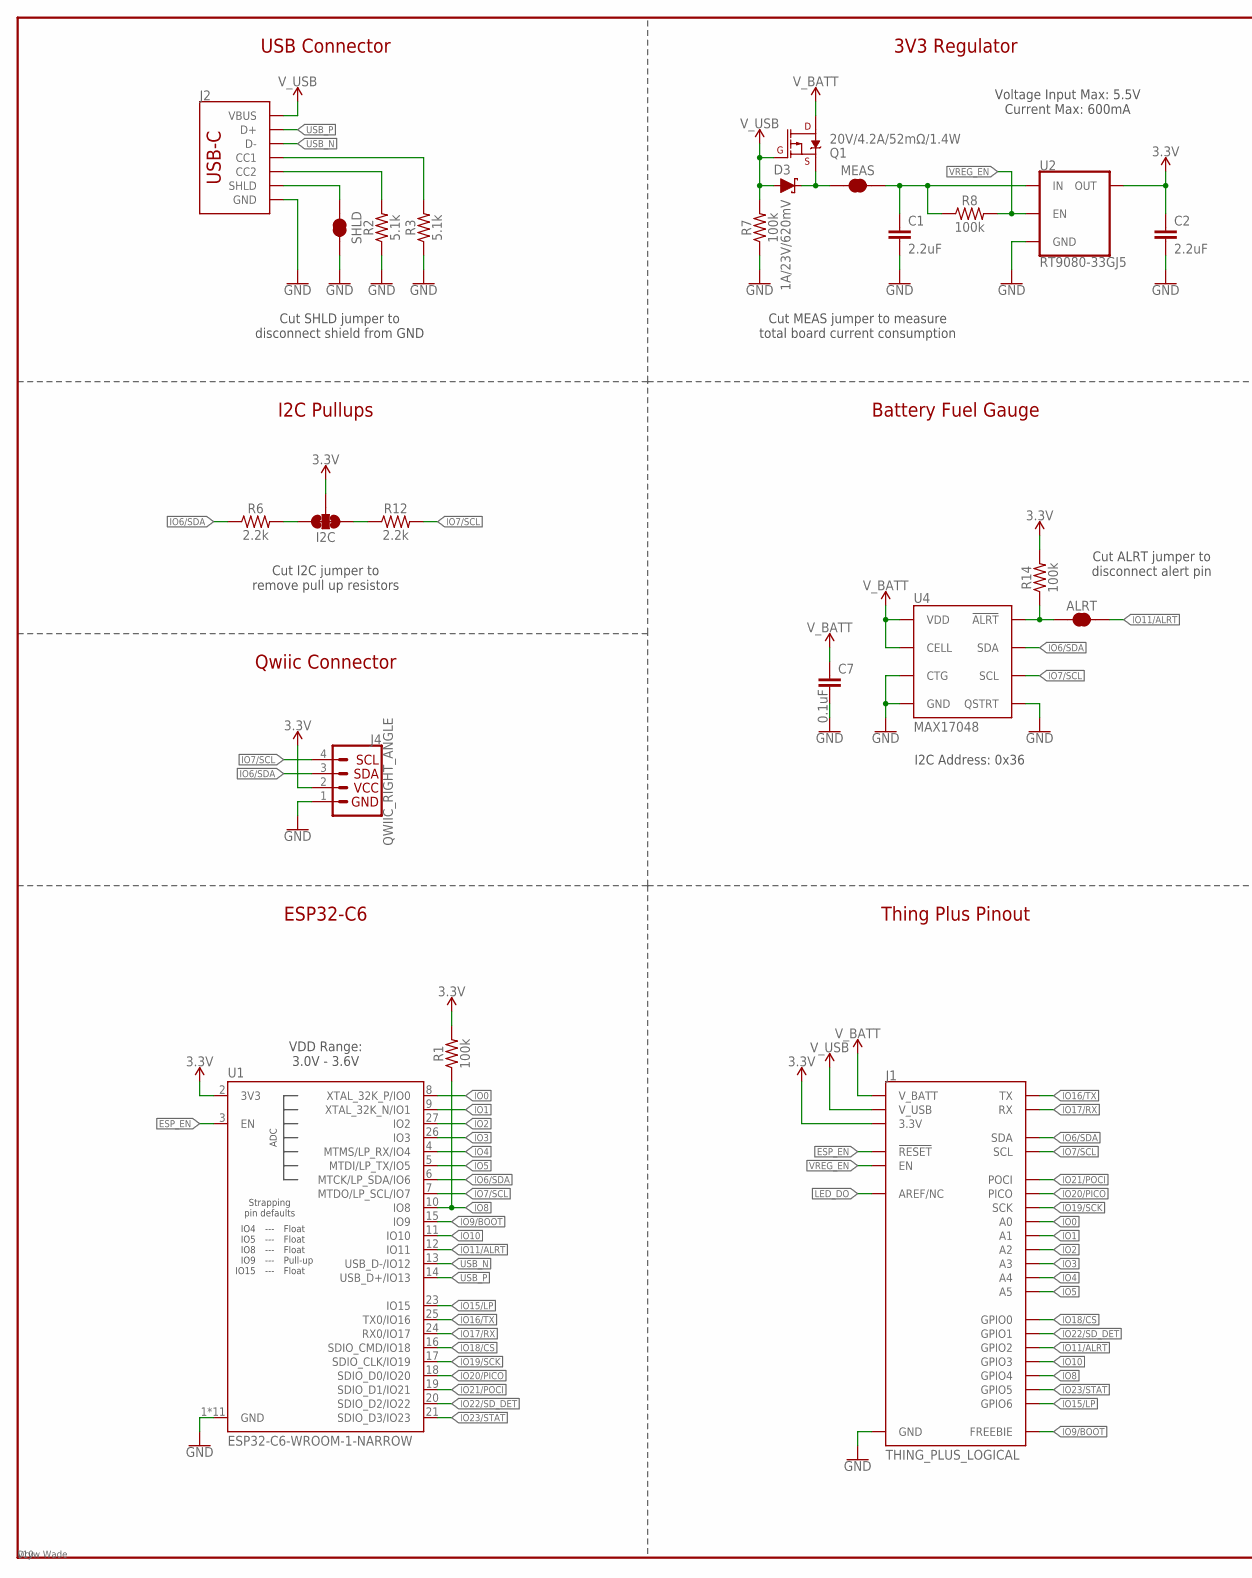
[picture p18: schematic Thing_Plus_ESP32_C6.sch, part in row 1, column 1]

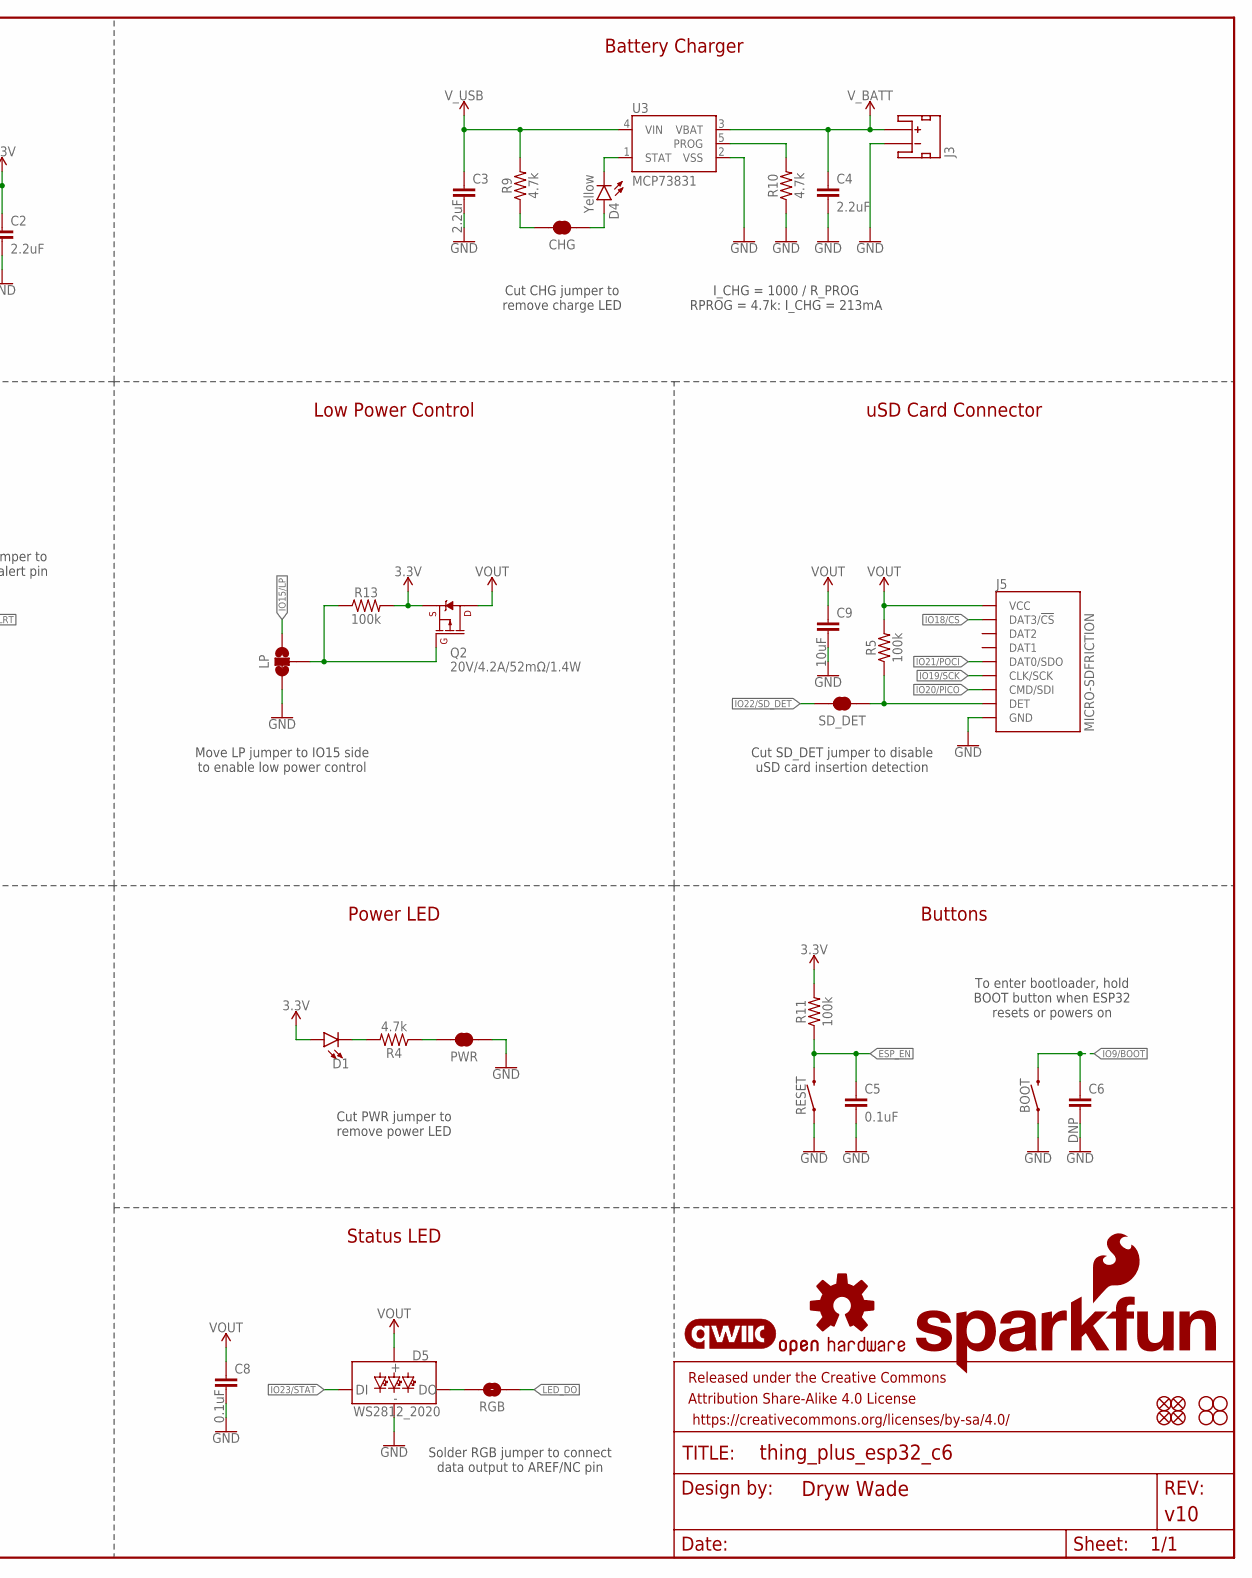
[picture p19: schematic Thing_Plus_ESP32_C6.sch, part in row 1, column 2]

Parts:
ALRT: JUMPER-SMT_2_NC_TRACE_SILK; SMT-JUMPER_2_NC_TRACE_SILK
BOOT: MOMENTARY-SWITCH-SPST-SMD-4.6X2.8MM; TACTILE_SWITCH_SMD_4.6X2.8MM
C1, C2, C3, C4: 2.2uF; 0603
C5, C7, C8: 0.1uF; 0603
C6: DNP; 0603
C9: 10uF; 0603
CHG: JUMPER-SMT_2_NC_TRACE_SILK; SMT-JUMPER_2_NC_TRACE_SILK
D1: LED-RED_0603-KB; LED-0603
D3: 1A/23V/620mV; SOD-323
D4: Yellow; LED-0603
D5: WS2812_2020; WS2812-2020
FD1, FD2, FD3, FD4: FIDUCIALUFIDUCIAL; FIDUCIAL-MICRO
FRAME1: FRAME-LEDGER; CREATIVE_COMMONS
H1, H2, H3, H4: STAND-OFF
I2C: JUMPER-SMT_3_2-NC_TRACE_SILK; SMT-JUMPER_3_2-NC_TRACE_SILK
J1: THING_PLUS_LOGICAL; THING_PLUS
J2: USB_C_4-LAYER_PADS; USB-C-16P_4LAYER-PADS
J3: JST_2MM_MALE; JST-2-SMD
J4: QWIIC_RIGHT_ANGLE; JST04_1MM_RA
J5: MICRO-SDFRICTION; MICROSD_TINY
LOGO1: SFE_LOGO_NAME_FLAME.1_INCH; SFE_LOGO_NAME_FLAME_.1
LOGO2: QWIIC_LOGO_4MM; QWIIC_4MM
LOGO3: OSHW-LOGOM; OSHW-LOGO-M
LP: JUMPER-SMT_3_1-NC_TRACE_SILK; SMT-JUMPER_3_1-NC_TRACE_SILK
MEAS: JUMPER-COMBO_2_NC_TRACE; COMBO-JUMPER_2_NC_TRACE
PWR: JUMPER-SMT_2_NC_TRACE_SILK; SMT-JUMPER_2_NC_TRACE_SILK
Q1, Q2: 20V/4.2A/52mΩ/1.4W; SOT23-3
R1, R5, R7, R8, R11, R13, R14: 100k; 0603
R2, R3: 5.1k; 0603
R4, R9, R10: 4.7k; 0603
R6, R12: 2.2k; 0603
RESET: MOMENTARY-SWITCH-SPST-SMD-4.6X2.8MM; TACTILE_SWITCH_SMD_4.6X2.8MM
RGB: JUMPER-SMT_2_NO_SILK; SMT-JUMPER_2_NO_SILK
SD_DET: JUMPER-SMT_2_NC_TRACE_SILK; SMT-JUMPER_2_NC_TRACE_SILK
SHLD: JUMPER-SMT_2_NC_TRACE_SILK; SMT-JUMPER_2_NC_TRACE_SILK
U1: ESP32-C6-WROOM-1-NARROW
U2: RT9080-33GJ5; SOT23-5
U3: MCP73831; SOT23-5
U4: MAX17048; DFN-8

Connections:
3.3V: C2.1, D1.A, I2C.2, J1.27 (3.3V), J4.2, Q2.2 (S), R1.2, R11.2, R13.2, R14.2, U1.2 (3V3), U2.5 (OUT)
ESP_EN: C5.1, J1.28 (!RESET), R11.1, RESET.3 (2), RESET.4 (2), U1.3 (EN)
GND: BOOT.1, BOOT.2 (1), C1.2, C2.2, C3.2, C4.2, C5.2, C6.2, C7.2, C8.2, C9.2, D5.GND, J1.25 (GND), J2.GND, J2.GND2 (GND), J3.1 (-), J4.1, J5.6 (GND), J5.GND1 (GND), J5.GND2 (GND), J5.GND3 (GND), J5.GND4 (GND), J5.GND5 (GND), J5.GND6 (GND), LP.3, PWR.1, R2.1, R3.1, R7.1, R10.1, RESET.1, RESET.2 (1), SHLD.2, U1.1 (GND), U1.28 (GND), U1.29 (GND), U1.30 (GND), U1.31 (GND), U1.32 (GND), U1.33 (GND), U1.34 (GND), U1.35 (GND), U1.36 (GND), U1.37 (GND), U2.2 (GND), U3.2 (VSS), U4.1 (CTG), U4.4 (GND), U4.6 (QSTRT), U4.9 (GND)
IO0: J1.24 (A0), U1.8 (XTAL_32K_P/IO0)
IO1: J1.23 (A1), U1.9 (XTAL_32K_N/IO1)
IO2: J1.22 (A2), U1.27 (IO2)
IO3: J1.21 (A3), U1.26 (IO3)
IO4: J1.20 (A4), U1.4 (MTMS/LP_RX/IO4)
IO5: J1.19 (A5), U1.5 (MTDI/LP_TX/IO5)
IO6/SDA: J1.1 (SDA), J4.3, R6.1, U1.6 (MTCK/LP_SDA/IO6), U4.8 (SDA)
IO7/SCL: J1.2 (SCL), J4.4, R12.2, U1.7 (MTDO/LP_SCL/IO7), U4.7 (SCL)
IO8: J1.5 (GPIO4), R1.1, U1.10 (IO8)
IO9/BOOT: BOOT.3 (2), BOOT.4 (2), C6.1, J1.13 (FREEBIE), U1.15 (IO9)
IO10: J1.6 (GPIO3), U1.11 (IO10)
IO11/!ALRT!: ALRT.2, J1.7 (GPIO2), U1.12 (IO11)
IO15/LP: J1.3 (GPIO6), LP.1, U1.23 (IO15)
IO16/TX: J1.14 (TX), U1.25 (TX0/IO16)
IO17/RX: J1.15 (RX), U1.24 (RX0/IO17)
IO18/!CS!: J1.9 (GPIO0), J5.2 (DAT3/!CS!), U1.16 (SDIO_CMD/IO18)
IO19/SCK: J1.18 (SCK), J5.5 (CLK/SCK), U1.17 (SDIO_CLK/IO19)
IO20/PICO: J1.17 (PICO), J5.3 (CMD/SDI), U1.18 (SDIO_D0/IO20)
IO21/POCI: J1.16 (POCI), J5.7 (DAT0/SDO), U1.19 (SDIO_D1/IO21)
IO22/!SD_DET!: J1.8 (GPIO1), SD_DET.2, U1.20 (SDIO_D2/IO22)
IO23/STAT: D5.DI, J1.4 (GPIO5), U1.21 (SDIO_D3/IO23)
LED_DO: J1.26 (AREF/NC), RGB.1
unnamed: D1.C, R4.2
unnamed: PWR.2, R4.1
unnamed: J5.9 (DET), R5.1, SD_DET.1
unnamed: D3.C, MEAS.1, MEAS.3 (1), Q1.2 (S)
unnamed: I2C.3, R6.2
unnamed: I2C.1, R12.1
unnamed: J2.B5 (CC2), R2.2
unnamed: J2.A5 (CC1), R3.2
unnamed: C1.1, MEAS.2, MEAS.4 (2), R8.1, U2.1 (IN)
unnamed: D4.C, U3.1 (STAT)
unnamed: CHG.1, D4.A
unnamed: CHG.2, R9.1
unnamed: R10.2, U3.5 (PROG)
unnamed: D5.DO, RGB.2
unnamed: LP.2, Q2.1 (G), R13.1
unnamed: ALRT.1, R14.1, U4.5 (!ALRT)
SHLD: J2.SHLD1 (SHLD), J2.SHLD2 (SHLD), J2.SHLD3 (SHLD), J2.SHLD4 (SHLD), SHLD.1
USB_N: J2.A7 (D-), J2.B7 (D-), U1.13 (USB_D-/IO12)
USB_P: J2.A6 (D+), J2.B6 (D+), U1.14 (USB_D+/IO13)
VOUT: C8.1, C9.1, D5.VCC, J5.4 (VCC), Q2.3 (D), R5.2
VREG_EN: J1.11 (EN), R8.2, U2.3 (EN)
V_BATT: C4.1, C7.1, J1.12 (V_BATT), J3.2 (+), Q1.3 (D), U3.3 (VBAT), U4.2 (CELL), U4.3 (VDD)
V_USB: C3.1, D3.A, J1.10 (V_USB), J2.VBUS1 (VBUS), J2.VBUS2 (VBUS), Q1.1 (G), R7.2, R9.2, U3.4 (VIN)

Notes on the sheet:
ESP32-C6
VDD Range: 3.0V - 3.6V
Buttons
3V3 Regulator
USB Connector
Battery Charger
Cut CHG jumper to remove charge LED
I_CHG = 1000 / R_PROG RPROG = 4.7k: I_CHG = 213mA
Power LED
Cut PWR jumper to remove power LED
Thing Plus Pinout
I2C Pullups
Cut I2C jumper to remove pull up resistors
I2C Address: 0x36
Qwiic Connector
Battery Fuel Gauge
uSD Card Connector
Cut SHLD jumper to disconnect shield from GND
Cut MEAS jumper to measure total board current consumption
Voltage Input Max: 5.5V Current Max: 600mA
Cut SD_DET jumper to disable uSD card insertion detection
Solder RGB jumper to connect data output to AREF/NC pin
Move LP jumper to IO15 side to enable low power control
To enter bootloader, hold BOOT button when ESP32 resets or powers on
Cut ALRT jumper to disconnect alert pin
Low Power Control
Status LED

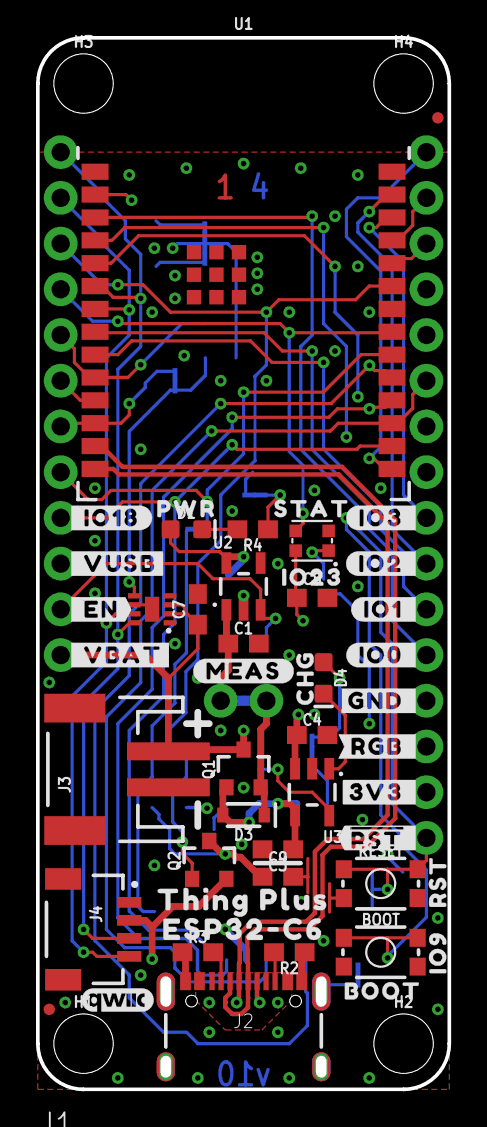
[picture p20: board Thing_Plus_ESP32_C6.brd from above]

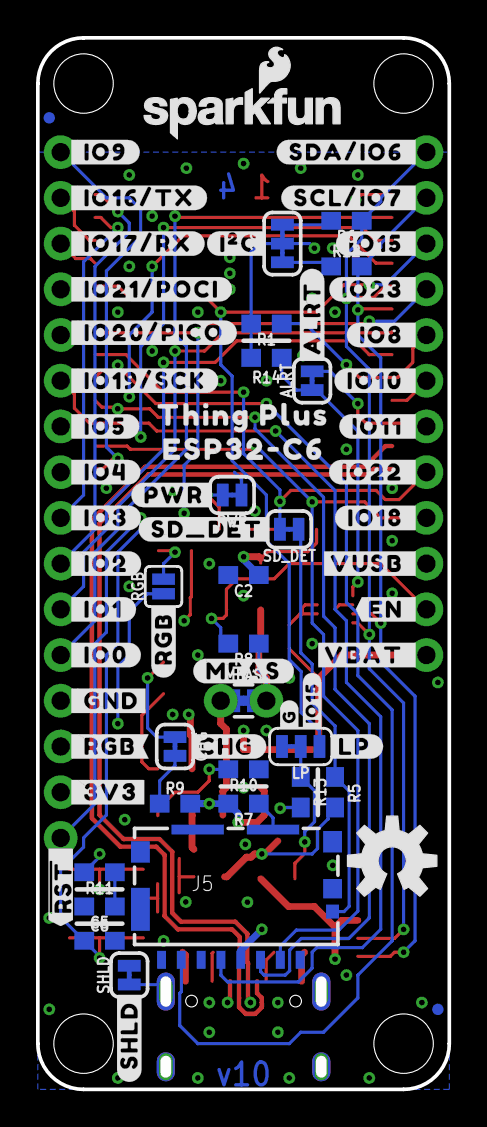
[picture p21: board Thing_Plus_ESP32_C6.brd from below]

Board: 4 copper layers, 22.9 x 58.4 mm, 125 parts (69 on the bottom side), 48 nets.

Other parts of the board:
U$1: #SHLD#0
U$2: #I�C#0
U$3: #_IO18#0
U$4: #_VUSB#0
U$5: #_VBAT#0
U$6: #_EN#0
U$7: #IO3_#0
U$8: #IO2_#0
U$9: #IO1_#0
U$10: #IO0_#0
U$11: #GND_#0
U$12: #3V3_#0
U$13, U$37: ##RST#_#0
U$14: #SDA#IO6_#0
U$15: #SCL#IO7_#0
U$16: #_IO21#POCI#0
U$17: #LP#0
U$18: #IO8_#0
U$19: #IO10_#0
U$20: #IO11_#0
U$21: #_IO19#SCK#0
U$22: #IO18_#0
U$23: #_IO9#0
U$24: #_IO16#TX#0
U$25: #_IO17#RX#0
U$26: #_IO20#PICO#0
U$27: #IO15#0
U$28: #ALRT#0
U$29: #_IO5#0
U$30: #_IO4#0
U$31: #_IO3#0
U$32: #_IO2#0
U$33: #_IO1#0
U$34: #_IO0#0
U$35: #_GND#0
U$36: #_3V3#0
U$38: #VUSB_#0
U$39: #VBAT_#0
U$40: #EN_#0
U$41: #SD_DET#0
U$42: BOOT0
U$43: RST0
U$44: IO90
U$45, U$47: THING_PLUS0
U$46, U$48: ESP32#C60
U$49, U$50: #MEAS#0
U$51: #CHG#0
U$52: #PWR#0
U$53: PWR0
U$54: CHG0
U$55: STAT0
U$56: #RGB#0
U$57: ORDERING_INSTRUCTIONS
U$58: #RGB_#0
U$59: #_RGB#0
U$62: IO230
U$63: #G#0
U$64: #IO23_#0
U$65: #IO15_#0
U$66: #IO22_#0

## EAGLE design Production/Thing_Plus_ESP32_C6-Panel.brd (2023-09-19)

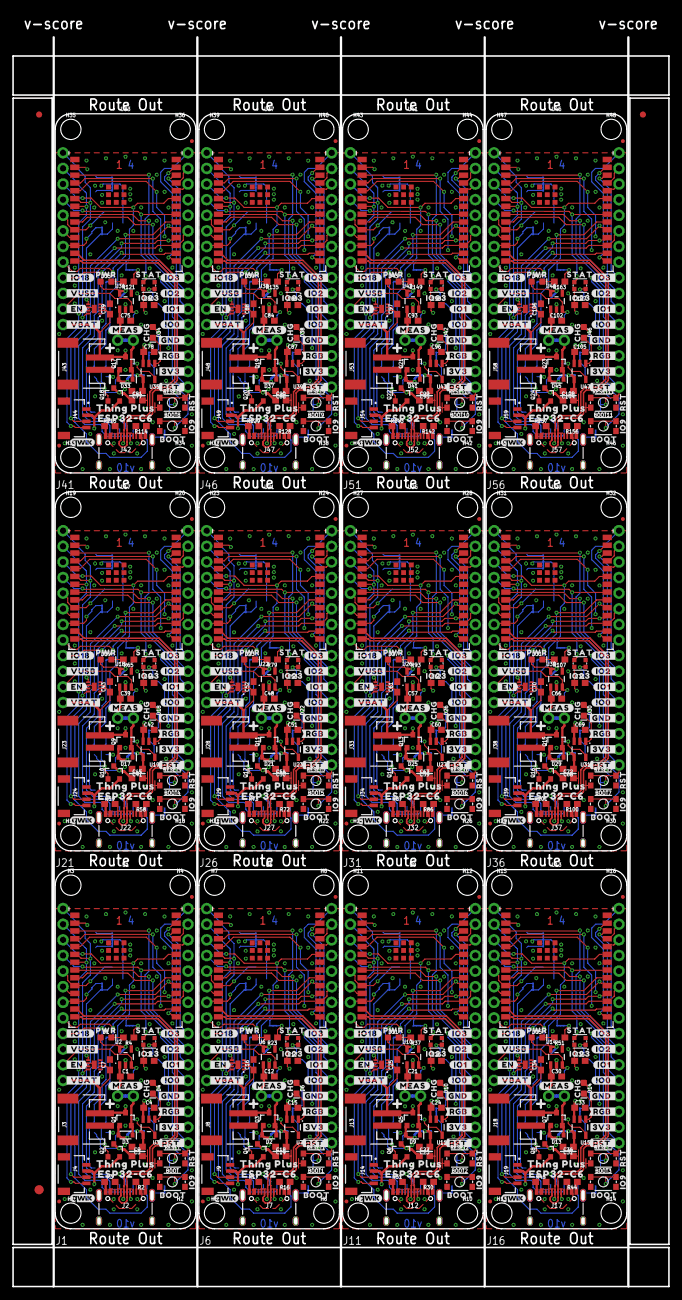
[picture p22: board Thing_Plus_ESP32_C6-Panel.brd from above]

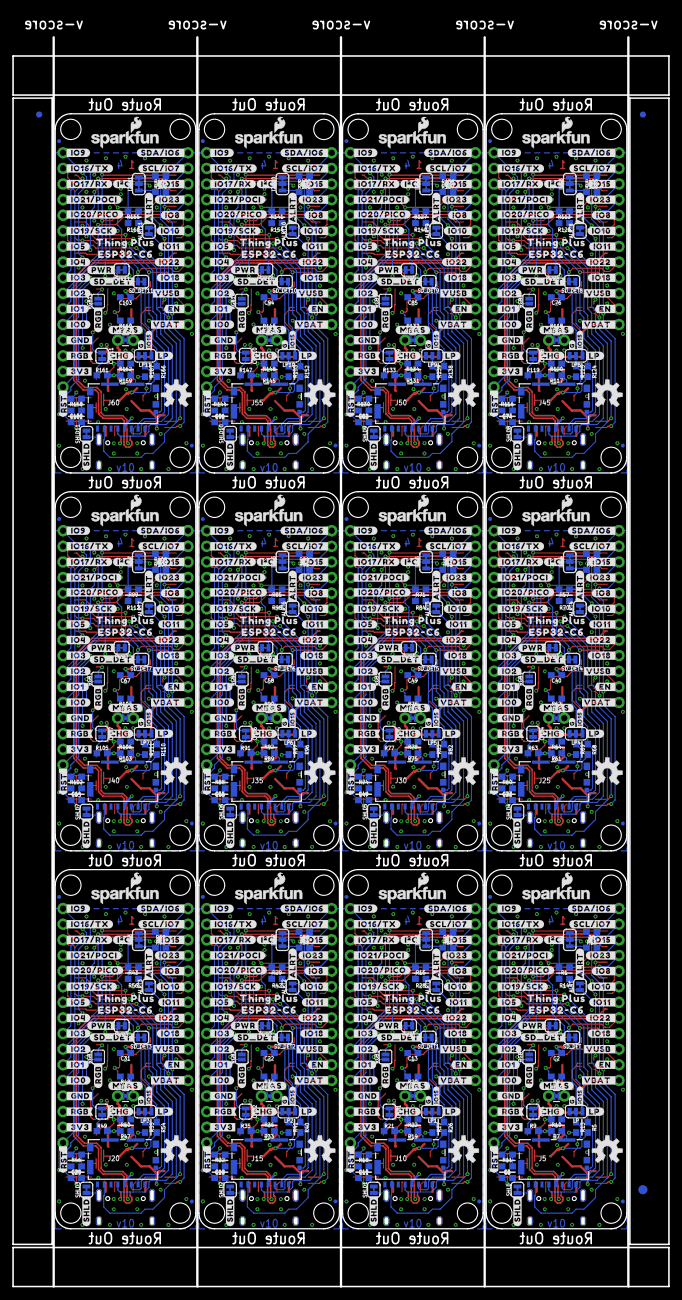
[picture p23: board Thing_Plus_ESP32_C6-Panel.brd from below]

Board: 4 copper layers, 106.7 x 203.2 mm, 1482 parts (831 on the bottom side), 576 nets.

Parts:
ALRT, ALRT1, ALRT2, ALRT3, ALRT4, ALRT5, ALRT6, ALRT7, ALRT8, ALRT9, ALRT10, ALRT11: JUMPER-SMT_2_NC_TRACE_SILK; SMT-JUMPER_2_NC_TRACE_SILK
BOOT, BOOT1, BOOT2, BOOT3, BOOT4, BOOT5, BOOT6, BOOT7, BOOT8, BOOT9, BOOT10, BOOT11: MOMENTARY-SWITCH-SPST-SMD-4.6X2.8MM; TACTILE_SWITCH_SMD_4.6X2.8MM
C1, C2, C3, C4, C12, C13, C14, C15, C21, C22, C23, C24, C30, C31, C32, C33, C39, C40, C41, C42, C48, C49, C50, C51, C57, C58, C59, C60, C66, C67, C68, C69, C75, C76, C77, C78, C84, C85, C86, C87, C93, C94, C95, C96, C102, C103, C104, C105: 2.2uF; 0603
C5, C7, C8, C10, C16, C17, C19, C25, C26, C28, C34, C35, C37, C43, C44, C46, C52, C53, C55, C61, C62, C64, C70, C71, C73, C79, C80, C82, C88, C89, C91, C97, C98, C100, C106, C107: 0.1uF; 0603
C6, C11, C20, C29, C38, C47, C56, C65, C74, C83, C92, C101: DNP; 0603
C9, C18, C27, C36, C45, C54, C63, C72, C81, C90, C99, C108: 10uF; 0603
CHG, CHG1, CHG2, CHG3, CHG4, CHG5, CHG6, CHG7, CHG8, CHG9, CHG10, CHG11: JUMPER-SMT_2_NC_TRACE_SILK; SMT-JUMPER_2_NC_TRACE_SILK
D1, D7, D11, D15, D19, D23, D27, D31, D35, D39, D43, D47: LED-0603
D2, D3, D9, D13, D17, D21, D25, D29, D33, D37, D41, D45: 1A/23V/620mV; SOD-323
D4, D6, D10, D14, D18, D22, D26, D30, D34, D38, D42, D46: Yellow; LED-0603
D5, D8, D12, D16, D20, D24, D28, D32, D36, D40, D44, D48: WS2812_2020; WS2812-2020
E$1, E$2, E$3, E$4: FIDUCIAL-1X2
E$5, E$6: FIDUCIAL-1.5X3
FD1, FD2, FD3, FD4, FD5, FD6, FD7, FD8, FD9, FD10, FD11, FD12, FD13, FD14, FD15, FD16, FD17, FD18, FD19, FD20, FD21, FD22, FD23, FD24, FD25, FD26, FD27, FD28, FD29, FD30, FD31, FD32, FD33, FD34, FD35, FD36, FD37, FD38, FD39, FD40, FD41, FD42, FD43, FD44, FD45, FD46, FD47, FD48: FIDUCIALUFIDUCIAL; FIDUCIAL-MICRO
H1, H2, H3, H4, H5, H6, H7, H8, H9, H10, H11, H12, H13, H14, H15, H16, H17, H18, H19, H20, H21, H22, H23, H24, H25, H26, H27, H28, H29, H30, H31, H32, H33, H34, H35, H36, H37, H38, H39, H40, H41, H42, H43, H44, H45, H46, H47, H48: STAND-OFF
I2C, I2C1, I2C2, I2C3, I2C4, I2C5, I2C6, I2C7, I2C8, I2C9, I2C10, I2C11: JUMPER-SMT_3_2-NC_TRACE_SILK; SMT-JUMPER_3_2-NC_TRACE_SILK
J1, J6, J11, J16, J21, J26, J31, J36, J41, J46, J51, J56: THING_PLUS_LOGICAL; THING_PLUS
J2, J7, J12, J17, J22, J27, J32, J37, J42, J47, J52, J57: USB-C-16P_4LAYER-PADS
J3, J8, J13, J18, J23, J28, J33, J38, J43, J48, J53, J58: JST-2-SMD
J4, J9, J14, J19, J24, J29, J34, J39, J44, J49, J54, J59: QWIIC_RIGHT_ANGLE; JST04_1MM_RA
J5, J10, J15, J20, J25, J30, J35, J40, J45, J50, J55, J60: MICRO-SDFRICTION; MICROSD_TINY
LOGO1, LOGO4, LOGO7, LOGO10, LOGO13, LOGO16, LOGO19, LOGO22, LOGO25, LOGO28, LOGO31, LOGO34: SFE_LOGO_NAME_FLAME.1_INCH; SFE_LOGO_NAME_FLAME_.1
LOGO2, LOGO5, LOGO8, LOGO11, LOGO14, LOGO17, LOGO20, LOGO23, LOGO26, LOGO29, LOGO32, LOGO35: QWIIC_LOGO_4MM; QWIIC_4MM
LOGO3, LOGO6, LOGO9, LOGO12, LOGO15, LOGO18, LOGO21, LOGO24, LOGO27, LOGO30, LOGO33, LOGO36: OSHW-LOGOM; OSHW-LOGO-M
LP, LP1, LP2, LP3, LP4, LP5, LP6, LP7, LP8, LP9, LP10, LP11: JUMPER-SMT_3_1-NC_TRACE_SILK; SMT-JUMPER_3_1-NC_TRACE_SILK
MEAS, MEAS1, MEAS2, MEAS3, MEAS4, MEAS5, MEAS6, MEAS7, MEAS8, MEAS9, MEAS10, MEAS11: JUMPER-COMBO_2_NC_TRACE; COMBO-JUMPER_2_NC_TRACE
PWR, PWR1, PWR2, PWR3, PWR4, PWR5, PWR6, PWR7, PWR8, PWR9, PWR10, PWR11: JUMPER-SMT_2_NC_TRACE_SILK; SMT-JUMPER_2_NC_TRACE_SILK
Q1, Q2, Q3, Q4, Q5, Q6, Q7, Q8, Q9, Q10, Q11, Q12, Q13, Q14, Q15, Q16, Q17, Q18, Q19, Q20, Q21, Q22, Q23, Q24: 20V/4.2A/52mΩ/1.4W; SOT23-3
R1, R5, R7, R8, R11, R13, R14, R15, R18, R19, R20, R26, R27, R28, R29, R32, R33, R34, R40, R41, R42, R43, R46, R47, R48, R54, R55, R56, R57, R60, R61, R62, R68, R69, R70, R71, R74, R75, R76, R82, R83, R84, R85, R88, R89, R90, R96, R97, R98, R99, R102, R103, R104, R110, R111, R112, R113, R116, R117, R118, R124, R125, R126, R127, R130, R131, R132, R138, R139, R140, R141, R144, R145, R146, R152, R153, R154, R155, R158, R159, R160, R166, R167, R168: 100k; 0603
R2, R3, R16, R17, R30, R31, R44, R45, R58, R59, R72, R73, R86, R87, R100, R101, R114, R115, R128, R129, R142, R143, R156, R157: 5.1k; 0603
R4, R9, R10, R21, R22, R23, R35, R36, R37, R49, R50, R51, R63, R64, R65, R77, R78, R79, R91, R92, R93, R105, R106, R107, R119, R120, R121, R133, R134, R135, R147, R148, R149, R161, R162, R163: 4.7k; 0603
R6, R12, R24, R25, R38, R39, R52, R53, R66, R67, R80, R81, R94, R95, R108, R109, R122, R123, R136, R137, R150, R151, R164, R165: 2.2k; 0603
RESET, RESET1, RESET2, RESET3, RESET4, RESET5, RESET6, RESET7, RESET8, RESET9, RESET10, RESET11: MOMENTARY-SWITCH-SPST-SMD-4.6X2.8MM; TACTILE_SWITCH_SMD_4.6X2.8MM
RGB, RGB1, RGB2, RGB3, RGB4, RGB5, RGB6, RGB7, RGB8, RGB9, RGB10, RGB11: JUMPER-SMT_2_NO_SILK; SMT-JUMPER_2_NO_SILK
SD_DET, SD_DET1, SD_DET2, SD_DET3, SD_DET4, SD_DET5, SD_DET6, SD_DET7, SD_DET8, SD_DET9, SD_DET10, SD_DET11: JUMPER-SMT_2_NC_TRACE_SILK; SMT-JUMPER_2_NC_TRACE_SILK
SHLD, SHLD1, SHLD2, SHLD3, SHLD4, SHLD5, SHLD6, SHLD7, SHLD8, SHLD9, SHLD10, SHLD11: JUMPER-SMT_2_NC_TRACE_SILK; SMT-JUMPER_2_NC_TRACE_SILK
U1, U5, U9, U13, U17, U21, U25, U29, U33, U37, U41, U45: ESP32-C6-WROOM-1-NARROW
U2, U6, U10, U14, U18, U22, U26, U30, U34, U38, U42, U46: RT9080-33GJ5; SOT23-5
U3, U7, U11, U15, U19, U23, U27, U31, U35, U39, U43, U47: MCP73831; SOT23-5
U4, U8, U12, U16, U20, U24, U28, U32, U36, U40, U44, U48: MAX17048; DFN-8
U$1, U$57, U$127, U$190, U$253, U$316, U$379, U$442, U$505, U$568, U$631, U$694: #SHLD#0
U$2, U$60, U$128, U$191, U$254, U$317, U$380, U$443, U$506, U$569, U$632, U$695: #I�C#0
U$3, U$61, U$129, U$192, U$255, U$318, U$381, U$444, U$507, U$570, U$633, U$696: #_IO18#0
U$4, U$67, U$130, U$193, U$256, U$319, U$382, U$445, U$508, U$571, U$634, U$697: #_VUSB#0
U$5, U$68, U$131, U$194, U$257, U$320, U$383, U$446, U$509, U$572, U$635, U$698: #_VBAT#0
U$6, U$69, U$132, U$195, U$258, U$321, U$384, U$447, U$510, U$573, U$636, U$699: #_EN#0
U$7, U$70, U$133, U$196, U$259, U$322, U$385, U$448, U$511, U$574, U$637, U$700: #IO3_#0
U$8, U$71, U$134, U$197, U$260, U$323, U$386, U$449, U$512, U$575, U$638, U$701: #IO2_#0
U$9, U$72, U$135, U$198, U$261, U$324, U$387, U$450, U$513, U$576, U$639, U$702: #IO1_#0
U$10, U$73, U$136, U$199, U$262, U$325, U$388, U$451, U$514, U$577, U$640, U$703: #IO0_#0
U$11, U$74, U$137, U$200, U$263, U$326, U$389, U$452, U$515, U$578, U$641, U$704: #GND_#0
U$12, U$75, U$138, U$201, U$264, U$327, U$390, U$453, U$516, U$579, U$642, U$705: #3V3_#0
U$13, U$37, U$76, U$97, U$139, U$160, U$202, U$223, U$265, U$286, U$328, U$349, U$391, U$412, U$454, U$475, U$517, U$538, U$580, U$601, U$643, U$664, U$706, U$727: ##RST#_#0
U$14, U$77, U$140, U$203, U$266, U$329, U$392, U$455, U$518, U$581, U$644, U$707: #SDA#IO6_#0
U$15, U$78, U$141, U$204, U$267, U$330, U$393, U$456, U$519, U$582, U$645, U$708: #SCL#IO7_#0
U$16, U$121, U$184, U$247, U$310, U$373, U$436, U$499, U$562, U$625, U$688, U$751: #_IO21#POCI#0
U$17, U$124, U$187, U$250, U$313, U$376, U$439, U$502, U$565, U$628, U$691, U$754: #LP#0
U$18, U$79, U$142, U$205, U$268, U$331, U$394, U$457, U$520, U$583, U$646, U$709: #IO8_#0
U$19, U$80, U$143, U$206, U$269, U$332, U$395, U$458, U$521, U$584, U$647, U$710: #IO10_#0
U$20, U$81, U$144, U$207, U$270, U$333, U$396, U$459, U$522, U$585, U$648, U$711: #IO11_#0
U$21, U$122, U$185, U$248, U$311, U$374, U$437, U$500, U$563, U$626, U$689, U$752: #_IO19#SCK#0
U$22, U$82, U$145, U$208, U$271, U$334, U$397, U$460, U$523, U$586, U$649, U$712: #IO18_#0
U$23, U$83, U$146, U$209, U$272, U$335, U$398, U$461, U$524, U$587, U$650, U$713: #_IO9#0
U$24, U$84, U$147, U$210, U$273, U$336, U$399, U$462, U$525, U$588, U$651, U$714: #_IO16#TX#0
U$25, U$85, U$148, U$211, U$274, U$337, U$400, U$463, U$526, U$589, U$652, U$715: #_IO17#RX#0
U$26, U$123, U$186, U$249, U$312, U$375, U$438, U$501, U$564, U$627, U$690, U$753: #_IO20#PICO#0
U$27, U$125, U$188, U$251, U$314, U$377, U$440, U$503, U$566, U$629, U$692, U$755: #IO15#0
U$28, U$126, U$189, U$252, U$315, U$378, U$441, U$504, U$567, U$630, U$693, U$756: #ALRT#0
U$29, U$86, U$149, U$212, U$275, U$338, U$401, U$464, U$527, U$590, U$653, U$716: #_IO5#0
U$30, U$87, U$150, U$213, U$276, U$339, U$402, U$465, U$528, U$591, U$654, U$717: #_IO4#0
U$31, U$88, U$151, U$214, U$277, U$340, U$403, U$466, U$529, U$592, U$655, U$718: #_IO3#0
U$32, U$89, U$152, U$215, U$278, U$341, U$404, U$467, U$530, U$593, U$656, U$719: #_IO2#0
U$33, U$90, U$153, U$216, U$279, U$342, U$405, U$468, U$531, U$594, U$657, U$720: #_IO1#0
U$34, U$91, U$154, U$217, U$280, U$343, U$406, U$469, U$532, U$595, U$658, U$721: #_IO0#0
U$35, U$92, U$155, U$218, U$281, U$344, U$407, U$470, U$533, U$596, U$659, U$722: #_GND#0
U$36, U$93, U$156, U$219, U$282, U$345, U$408, U$471, U$534, U$597, U$660, U$723: #_3V3#0
U$38, U$94, U$157, U$220, U$283, U$346, U$409, U$472, U$535, U$598, U$661, U$724: #VUSB_#0
U$39, U$95, U$158, U$221, U$284, U$347, U$410, U$473, U$536, U$599, U$662, U$725: #VBAT_#0
U$40, U$96, U$159, U$222, U$285, U$348, U$411, U$474, U$537, U$600, U$663, U$726: #EN_#0
U$41, U$98, U$161, U$224, U$287, U$350, U$413, U$476, U$539, U$602, U$665, U$728: #SD_DET#0
U$42, U$99, U$162, U$225, U$288, U$351, U$414, U$477, U$540, U$603, U$666, U$729: BOOT0
U$43, U$100, U$163, U$226, U$289, U$352, U$415, U$478, U$541, U$604, U$667, U$730: RST0
U$44, U$101, U$164, U$227, U$290, U$353, U$416, U$479, U$542, U$605, U$668, U$731: IO90
U$45, U$47, U$102, U$104, U$165, U$167, U$228, U$230, U$291, U$293, U$354, U$356, U$417, U$419, U$480, U$482, U$543, U$545, U$606, U$608, U$669, U$671, U$732, U$734: THING_PLUS0
U$46, U$48, U$103, U$105, U$166, U$168, U$229, U$231, U$292, U$294, U$355, U$357, U$418, U$420, U$481, U$483, U$544, U$546, U$607, U$609, U$670, U$672, U$733, U$735: ESP32#C60
U$49, U$50, U$106, U$107, U$169, U$170, U$232, U$233, U$295, U$296, U$358, U$359, U$421, U$422, U$484, U$485, U$547, U$548, U$610, U$611, U$673, U$674, U$736, U$737: #MEAS#0
U$51, U$108, U$171, U$234, U$297, U$360, U$423, U$486, U$549, U$612, U$675, U$738: #CHG#0
U$52, U$109, U$172, U$235, U$298, U$361, U$424, U$487, U$550, U$613, U$676, U$739: #PWR#0
U$53, U$110, U$173, U$236, U$299, U$362, U$425, U$488, U$551, U$614, U$677, U$740: PWR0
U$54, U$111, U$174, U$237, U$300, U$363, U$426, U$489, U$552, U$615, U$678, U$741: CHG0
U$55, U$112, U$175, U$238, U$301, U$364, U$427, U$490, U$553, U$616, U$679, U$742: STAT0
U$56, U$113, U$176, U$239, U$302, U$365, U$428, U$491, U$554, U$617, U$680, U$743: #RGB#0
U$58, U$114, U$177, U$240, U$303, U$366, U$429, U$492, U$555, U$618, U$681, U$744: #RGB_#0
U$59, U$115, U$178, U$241, U$304, U$367, U$430, U$493, U$556, U$619, U$682, U$745: #_RGB#0
U$62, U$117, U$180, U$243, U$306, U$369, U$432, U$495, U$558, U$621, U$684, U$747: IO230
U$63, U$116, U$179, U$242, U$305, U$368, U$431, U$494, U$557, U$620, U$683, U$746: #G#0
U$64, U$119, U$182, U$245, U$308, U$371, U$434, U$497, U$560, U$623, U$686, U$749: #IO23_#0
U$65, U$118, U$181, U$244, U$307, U$370, U$433, U$496, U$559, U$622, U$685, U$748: #IO15_#0
U$66, U$120, U$183, U$246, U$309, U$372, U$435, U$498, U$561, U$624, U$687, U$750: #IO22_#0

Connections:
3.3V: C2.1, D1.A, I2C.2, J1.27, J4.2, Q2.2, R1.2, R11.2, R13.2, R14.2, U1.2, U2.5
3.3V1: C13.1, D7.A, I2C1.2, J6.27, J9.2, Q4.2, R15.2, R18.2, R27.2, R28.2, U5.2, U6.5
3.3V2: C22.1, D11.A, I2C2.2, J11.27, J14.2, Q6.2, R29.2, R32.2, R41.2, R42.2, U9.2, U10.5
3.3V3: C31.1, D15.A, I2C3.2, J16.27, J19.2, Q8.2, R43.2, R46.2, R55.2, R56.2, U13.2, U14.5
3.3V4: C40.1, D19.A, I2C4.2, J21.27, J24.2, Q10.2, R57.2, R60.2, R69.2, R70.2, U17.2, U18.5
3.3V5: C49.1, D23.A, I2C5.2, J26.27, J29.2, Q12.2, R71.2, R74.2, R83.2, R84.2, U21.2, U22.5
3.3V6: C58.1, D27.A, I2C6.2, J31.27, J34.2, Q14.2, R85.2, R88.2, R97.2, R98.2, U25.2, U26.5
3.3V7: C67.1, D31.A, I2C7.2, J36.27, J39.2, Q16.2, R99.2, R102.2, R111.2, R112.2, U29.2, U30.5
3.3V8: C76.1, D35.A, I2C8.2, J41.27, J44.2, Q18.2, R113.2, R116.2, R125.2, R126.2, U33.2, U34.5
3.3V9: C85.1, D39.A, I2C9.2, J46.27, J49.2, Q20.2, R127.2, R130.2, R139.2, R140.2, U37.2, U38.5
3.3V10: C94.1, D43.A, I2C10.2, J51.27, J54.2, Q22.2, R141.2, R144.2, R153.2, R154.2, U41.2, U42.5
3.3V11: C103.1, D47.A, I2C11.2, J56.27, J59.2, Q24.2, R155.2, R158.2, R167.2, R168.2, U45.2, U46.5
ESP_EN: C5.1, J1.28, R11.1, RESET.3, RESET.4, U1.3
ESP_EN1: C10.1, J6.28, R18.1, RESET1.3, RESET1.4, U5.3
ESP_EN2: C19.1, J11.28, R32.1, RESET2.3, RESET2.4, U9.3
ESP_EN3: C28.1, J16.28, R46.1, RESET3.3, RESET3.4, U13.3
ESP_EN4: C37.1, J21.28, R60.1, RESET4.3, RESET4.4, U17.3
ESP_EN5: C46.1, J26.28, R74.1, RESET5.3, RESET5.4, U21.3
ESP_EN6: C55.1, J31.28, R88.1, RESET6.3, RESET6.4, U25.3
ESP_EN7: C64.1, J36.28, R102.1, RESET7.3, RESET7.4, U29.3
ESP_EN8: C73.1, J41.28, R116.1, RESET8.3, RESET8.4, U33.3
ESP_EN9: C82.1, J46.28, R130.1, RESET9.3, RESET9.4, U37.3
ESP_EN10: C91.1, J51.28, R144.1, RESET10.3, RESET10.4, U41.3
ESP_EN11: C100.1, J56.28, R158.1, RESET11.3, RESET11.4, U45.3
GND: BOOT.1, BOOT.2, C1.2, C2.2, C3.2, C4.2, C5.2, C6.2, C7.2, C8.2, C9.2, D5.GND, J1.25, J2.GND, J2.GND2, J3.1, J4.1, J5.6, J5.GND1, J5.GND2, J5.GND3, J5.GND4, J5.GND5, J5.GND6, LP.3, PWR.1, R2.1, R3.1, R7.1, R10.1, RESET.1, RESET.2, SHLD.2, U1.1, U1.28, U1.29, U1.30, U1.31, U1.32, U1.33, U1.34, U1.35, U1.36, U1.37, U2.2, U3.2, U4.1, U4.4, U4.6, U4.9
GND1: BOOT1.1, BOOT1.2, C10.2, C11.2, C12.2, C13.2, C14.2, C15.2, C16.2, C17.2, C18.2, D8.GND, J6.25, J7.GND, J7.GND2, J8.1, J9.1, J10.6, J10.GND1, J10.GND2, J10.GND3, J10.GND4, J10.GND5, J10.GND6, LP1.3, PWR1.1, R16.1, R17.1, R19.1, R22.1, RESET1.1, RESET1.2, SHLD1.2, U5.1, U5.28, U5.29, U5.30, U5.31, U5.32, U5.33, U5.34, U5.35, U5.36, U5.37, U6.2, U7.2, U8.1, U8.4, U8.6, U8.9
GND2: BOOT2.1, BOOT2.2, C19.2, C20.2, C21.2, C22.2, C23.2, C24.2, C25.2, C26.2, C27.2, D12.GND, J11.25, J12.GND, J12.GND2, J13.1, J14.1, J15.6, J15.GND1, J15.GND2, J15.GND3, J15.GND4, J15.GND5, J15.GND6, LP2.3, PWR2.1, R30.1, R31.1, R33.1, R36.1, RESET2.1, RESET2.2, SHLD2.2, U9.1, U9.28, U9.29, U9.30, U9.31, U9.32, U9.33, U9.34, U9.35, U9.36, U9.37, U10.2, U11.2, U12.1, U12.4, U12.6, U12.9
GND3: BOOT3.1, BOOT3.2, C28.2, C29.2, C30.2, C31.2, C32.2, C33.2, C34.2, C35.2, C36.2, D16.GND, J16.25, J17.GND, J17.GND2, J18.1, J19.1, J20.6, J20.GND1, J20.GND2, J20.GND3, J20.GND4, J20.GND5, J20.GND6, LP3.3, PWR3.1, R44.1, R45.1, R47.1, R50.1, RESET3.1, RESET3.2, SHLD3.2, U13.1, U13.28, U13.29, U13.30, U13.31, U13.32, U13.33, U13.34, U13.35, U13.36, U13.37, U14.2, U15.2, U16.1, U16.4, U16.6, U16.9
GND4: BOOT4.1, BOOT4.2, C37.2, C38.2, C39.2, C40.2, C41.2, C42.2, C43.2, C44.2, C45.2, D20.GND, J21.25, J22.GND, J22.GND2, J23.1, J24.1, J25.6, J25.GND1, J25.GND2, J25.GND3, J25.GND4, J25.GND5, J25.GND6, LP4.3, PWR4.1, R58.1, R59.1, R61.1, R64.1, RESET4.1, RESET4.2, SHLD4.2, U17.1, U17.28, U17.29, U17.30, U17.31, U17.32, U17.33, U17.34, U17.35, U17.36, U17.37, U18.2, U19.2, U20.1, U20.4, U20.6, U20.9
GND5: BOOT5.1, BOOT5.2, C46.2, C47.2, C48.2, C49.2, C50.2, C51.2, C52.2, C53.2, C54.2, D24.GND, J26.25, J27.GND, J27.GND2, J28.1, J29.1, J30.6, J30.GND1, J30.GND2, J30.GND3, J30.GND4, J30.GND5, J30.GND6, LP5.3, PWR5.1, R72.1, R73.1, R75.1, R78.1, RESET5.1, RESET5.2, SHLD5.2, U21.1, U21.28, U21.29, U21.30, U21.31, U21.32, U21.33, U21.34, U21.35, U21.36, U21.37, U22.2, U23.2, U24.1, U24.4, U24.6, U24.9
GND6: BOOT6.1, BOOT6.2, C55.2, C56.2, C57.2, C58.2, C59.2, C60.2, C61.2, C62.2, C63.2, D28.GND, J31.25, J32.GND, J32.GND2, J33.1, J34.1, J35.6, J35.GND1, J35.GND2, J35.GND3, J35.GND4, J35.GND5, J35.GND6, LP6.3, PWR6.1, R86.1, R87.1, R89.1, R92.1, RESET6.1, RESET6.2, SHLD6.2, U25.1, U25.28, U25.29, U25.30, U25.31, U25.32, U25.33, U25.34, U25.35, U25.36, U25.37, U26.2, U27.2, U28.1, U28.4, U28.6, U28.9
GND7: BOOT7.1, BOOT7.2, C64.2, C65.2, C66.2, C67.2, C68.2, C69.2, C70.2, C71.2, C72.2, D32.GND, J36.25, J37.GND, J37.GND2, J38.1, J39.1, J40.6, J40.GND1, J40.GND2, J40.GND3, J40.GND4, J40.GND5, J40.GND6, LP7.3, PWR7.1, R100.1, R101.1, R103.1, R106.1, RESET7.1, RESET7.2, SHLD7.2, U29.1, U29.28, U29.29, U29.30, U29.31, U29.32, U29.33, U29.34, U29.35, U29.36, U29.37, U30.2, U31.2, U32.1, U32.4, U32.6, U32.9
GND8: BOOT8.1, BOOT8.2, C73.2, C74.2, C75.2, C76.2, C77.2, C78.2, C79.2, C80.2, C81.2, D36.GND, J41.25, J42.GND, J42.GND2, J43.1, J44.1, J45.6, J45.GND1, J45.GND2, J45.GND3, J45.GND4, J45.GND5, J45.GND6, LP8.3, PWR8.1, R114.1, R115.1, R117.1, R120.1, RESET8.1, RESET8.2, SHLD8.2, U33.1, U33.28, U33.29, U33.30, U33.31, U33.32, U33.33, U33.34, U33.35, U33.36, U33.37, U34.2, U35.2, U36.1, U36.4, U36.6, U36.9
GND9: BOOT9.1, BOOT9.2, C82.2, C83.2, C84.2, C85.2, C86.2, C87.2, C88.2, C89.2, C90.2, D40.GND, J46.25, J47.GND, J47.GND2, J48.1, J49.1, J50.6, J50.GND1, J50.GND2, J50.GND3, J50.GND4, J50.GND5, J50.GND6, LP9.3, PWR9.1, R128.1, R129.1, R131.1, R134.1, RESET9.1, RESET9.2, SHLD9.2, U37.1, U37.28, U37.29, U37.30, U37.31, U37.32, U37.33, U37.34, U37.35, U37.36, U37.37, U38.2, U39.2, U40.1, U40.4, U40.6, U40.9
GND10: BOOT10.1, BOOT10.2, C91.2, C92.2, C93.2, C94.2, C95.2, C96.2, C97.2, C98.2, C99.2, D44.GND, J51.25, J52.GND, J52.GND2, J53.1, J54.1, J55.6, J55.GND1, J55.GND2, J55.GND3, J55.GND4, J55.GND5, J55.GND6, LP10.3, PWR10.1, R142.1, R143.1, R145.1, R148.1, RESET10.1, RESET10.2, SHLD10.2, U41.1, U41.28, U41.29, U41.30, U41.31, U41.32, U41.33, U41.34, U41.35, U41.36, U41.37, U42.2, U43.2, U44.1, U44.4, U44.6, U44.9
GND11: BOOT11.1, BOOT11.2, C100.2, C101.2, C102.2, C103.2, C104.2, C105.2, C106.2, C107.2, C108.2, D48.GND, J56.25, J57.GND, J57.GND2, J58.1, J59.1, J60.6, J60.GND1, J60.GND2, J60.GND3, J60.GND4, J60.GND5, J60.GND6, LP11.3, PWR11.1, R156.1, R157.1, R159.1, R162.1, RESET11.1, RESET11.2, SHLD11.2, U45.1, U45.28, U45.29, U45.30, U45.31, U45.32, U45.33, U45.34, U45.35, U45.36, U45.37, U46.2, U47.2, U48.1, U48.4, U48.6, U48.9
IO0: J1.24, U1.8
IO1: J1.23, U1.9
IO2: J1.22, U1.27
IO3: J1.21, U1.26
IO4: J1.20, U1.4
IO5: J1.19, U1.5
IO6: J6.20, U5.4
IO6/SDA: J1.1, J4.3, R6.1, U1.6, U4.8
IO6/SDA1: J6.1, J9.3, R24.1, U5.6, U8.8
IO6/SDA2: J11.1, J14.3, R38.1, U9.6, U12.8
IO6/SDA3: J16.1, J19.3, R52.1, U13.6, U16.8
IO6/SDA4: J21.1, J24.3, R66.1, U17.6, U20.8
IO6/SDA5: J26.1, J29.3, R80.1, U21.6, U24.8
IO6/SDA6: J31.1, J34.3, R94.1, U25.6, U28.8
IO6/SDA7: J36.1, J39.3, R108.1, U29.6, U32.8
IO6/SDA8: J41.1, J44.3, R122.1, U33.6, U36.8
IO6/SDA9: J46.1, J49.3, R136.1, U37.6, U40.8
IO6/SDA10: J51.1, J54.3, R150.1, U41.6, U44.8
IO6/SDA11: J56.1, J59.3, R164.1, U45.6, U48.8
IO7: J6.19, U5.5
IO7/SCL: J1.2, J4.4, R12.2, U1.7, U4.7
IO7/SCL1: J6.2, J9.4, R25.2, U5.7, U8.7
IO7/SCL2: J11.2, J14.4, R39.2, U9.7, U12.7
IO7/SCL3: J16.2, J19.4, R53.2, U13.7, U16.7
IO7/SCL4: J21.2, J24.4, R67.2, U17.7, U20.7
IO7/SCL5: J26.2, J29.4, R81.2, U21.7, U24.7
IO7/SCL6: J31.2, J34.4, R95.2, U25.7, U28.7
IO7/SCL7: J36.2, J39.4, R109.2, U29.7, U32.7
IO7/SCL8: J41.2, J44.4, R123.2, U33.7, U36.7
IO7/SCL9: J46.2, J49.4, R137.2, U37.7, U40.7
IO7/SCL10: J51.2, J54.4, R151.2, U41.7, U44.7
IO7/SCL11: J56.2, J59.4, R165.2, U45.7, U48.7
IO8: J1.5, R1.1, U1.10
IO9: J6.22, U5.27
IO9/BOOT: BOOT.3, BOOT.4, C6.1, J1.13, U1.15
IO9/BOOT1: BOOT1.3, BOOT1.4, C11.1, J6.13, U5.15
IO9/BOOT2: BOOT2.3, BOOT2.4, C20.1, J11.13, U9.15
IO9/BOOT3: BOOT3.3, BOOT3.4, C29.1, J16.13, U13.15
IO9/BOOT4: BOOT4.3, BOOT4.4, C38.1, J21.13, U17.15
IO9/BOOT5: BOOT5.3, BOOT5.4, C47.1, J26.13, U21.15
IO9/BOOT6: BOOT6.3, BOOT6.4, C56.1, J31.13, U25.15
IO9/BOOT7: BOOT7.3, BOOT7.4, C65.1, J36.13, U29.15
IO9/BOOT8: BOOT8.3, BOOT8.4, C74.1, J41.13, U33.15
IO9/BOOT9: BOOT9.3, BOOT9.4, C83.1, J46.13, U37.15
IO9/BOOT10: BOOT10.3, BOOT10.4, C92.1, J51.13, U41.15
IO9/BOOT11: BOOT11.3, BOOT11.4, C101.1, J56.13, U45.15
IO10: J1.6, U1.11
IO11: J6.21, U5.26
IO11/!ALRT!: ALRT.2, J1.7, U1.12
IO11/!ALRT!1: ALRT1.2, J6.7, U5.12
IO11/!ALRT!2: ALRT2.2, J11.7, U9.12
IO11/!ALRT!3: ALRT3.2, J16.7, U13.12
IO11/!ALRT!4: ALRT4.2, J21.7, U17.12
IO11/!ALRT!5: ALRT5.2, J26.7, U21.12
IO11/!ALRT!6: ALRT6.2, J31.7, U25.12
IO11/!ALRT!7: ALRT7.2, J36.7, U29.12
IO11/!ALRT!8: ALRT8.2, J41.7, U33.12
IO11/!ALRT!9: ALRT9.2, J46.7, U37.12
IO11/!ALRT!10: ALRT10.2, J51.7, U41.12
IO11/!ALRT!11: ALRT11.2, J56.7, U45.12
IO12: J6.5, R15.1, U5.10
IO13: J6.24, U5.8
IO14: J6.23, U5.9
IO15: J6.6, U5.11
IO15/LP: J1.3, LP.1, U1.23
IO15/LP1: J6.3, LP1.1, U5.23
IO15/LP2: J11.3, LP2.1, U9.23
IO15/LP3: J16.3, LP3.1, U13.23
IO15/LP4: J21.3, LP4.1, U17.23
IO15/LP5: J26.3, LP5.1, U21.23
IO15/LP6: J31.3, LP6.1, U25.23
IO15/LP7: J36.3, LP7.1, U29.23
IO15/LP8: J41.3, LP8.1, U33.23
IO15/LP9: J46.3, LP9.1, U37.23
IO15/LP10: J51.3, LP10.1, U41.23
IO15/LP11: J56.3, LP11.1, U45.23
IO16: J11.20, U9.4
IO16/TX: J1.14, U1.25
IO16/TX1: J6.14, U5.25
IO16/TX2: J11.14, U9.25
IO16/TX3: J16.14, U13.25
IO16/TX4: J21.14, U17.25
IO16/TX5: J26.14, U21.25
IO16/TX6: J31.14, U25.25
IO16/TX7: J36.14, U29.25
IO16/TX8: J41.14, U33.25
IO16/TX9: J46.14, U37.25
IO16/TX10: J51.14, U41.25
IO16/TX11: J56.14, U45.25
IO17: J11.19, U9.5
IO17/RX: J1.15, U1.24
IO17/RX1: J6.15, U5.24
IO17/RX2: J11.15, U9.24
IO17/RX3: J16.15, U13.24
IO17/RX4: J21.15, U17.24
IO17/RX5: J26.15, U21.24
IO17/RX6: J31.15, U25.24
IO17/RX7: J36.15, U29.24
IO17/RX8: J41.15, U33.24
IO17/RX9: J46.15, U37.24
IO17/RX10: J51.15, U41.24
IO17/RX11: J56.15, U45.24
IO18: J11.22, U9.27
IO18/!CS!: J1.9, J5.2, U1.16
IO18/!CS!1: J6.9, J10.2, U5.16
IO18/!CS!2: J11.9, J15.2, U9.16
IO18/!CS!3: J16.9, J20.2, U13.16
IO18/!CS!4: J21.9, J25.2, U17.16
IO18/!CS!5: J26.9, J30.2, U21.16
IO18/!CS!6: J31.9, J35.2, U25.16
IO18/!CS!7: J36.9, J40.2, U29.16
IO18/!CS!8: J41.9, J45.2, U33.16
IO18/!CS!9: J46.9, J50.2, U37.16
IO18/!CS!10: J51.9, J55.2, U41.16
IO18/!CS!11: J56.9, J60.2, U45.16
IO19: J11.21, U9.26
IO19/SCK: J1.18, J5.5, U1.17
IO19/SCK1: J6.18, J10.5, U5.17
IO19/SCK2: J11.18, J15.5, U9.17
IO19/SCK3: J16.18, J20.5, U13.17
IO19/SCK4: J21.18, J25.5, U17.17
IO19/SCK5: J26.18, J30.5, U21.17
IO19/SCK6: J31.18, J35.5, U25.17
IO19/SCK7: J36.18, J40.5, U29.17
IO19/SCK8: J41.18, J45.5, U33.17
IO19/SCK9: J46.18, J50.5, U37.17
IO19/SCK10: J51.18, J55.5, U41.17
IO19/SCK11: J56.18, J60.5, U45.17
IO20: J11.5, R29.1, U9.10
IO20/PICO: J1.17, J5.3, U1.18
IO20/PICO1: J6.17, J10.3, U5.18
IO20/PICO2: J11.17, J15.3, U9.18
IO20/PICO3: J16.17, J20.3, U13.18
IO20/PICO4: J21.17, J25.3, U17.18
IO20/PICO5: J26.17, J30.3, U21.18
IO20/PICO6: J31.17, J35.3, U25.18
IO20/PICO7: J36.17, J40.3, U29.18
IO20/PICO8: J41.17, J45.3, U33.18
IO20/PICO9: J46.17, J50.3, U37.18
IO20/PICO10: J51.17, J55.3, U41.18
IO20/PICO11: J56.17, J60.3, U45.18
IO21: J11.24, U9.8
IO21/POCI: J1.16, J5.7, U1.19
IO21/POCI1: J6.16, J10.7, U5.19
IO21/POCI2: J11.16, J15.7, U9.19
IO21/POCI3: J16.16, J20.7, U13.19
IO21/POCI4: J21.16, J25.7, U17.19
IO21/POCI5: J26.16, J30.7, U21.19
IO21/POCI6: J31.16, J35.7, U25.19
IO21/POCI7: J36.16, J40.7, U29.19
IO21/POCI8: J41.16, J45.7, U33.19
IO21/POCI9: J46.16, J50.7, U37.19
IO21/POCI10: J51.16, J55.7, U41.19
IO21/POCI11: J56.16, J60.7, U45.19
IO22: J11.23, U9.9
IO22/!SD_DET!: J1.8, SD_DET.2, U1.20
IO22/!SD_DET!1: J6.8, SD_DET1.2, U5.20
IO22/!SD_DET!2: J11.8, SD_DET2.2, U9.20
IO22/!SD_DET!3: J16.8, SD_DET3.2, U13.20
IO22/!SD_DET!4: J21.8, SD_DET4.2, U17.20
IO22/!SD_DET!5: J26.8, SD_DET5.2, U21.20
IO22/!SD_DET!6: J31.8, SD_DET6.2, U25.20
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

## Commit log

2023-06-20 Add ESP32-C6 documents
    SoC datasheet
    Module datasheet
    Hardware design guidelines
    Technical reference manual
2023-06-21 Add initial design
    Schematic needs to be organized
    SD connector needs to be routed, and have a couple pins assigned
    [Thing_Plus_ESP32_C6.brd, Thing_Plus_ESP32_C6.sch]
2023-06-26 Finish initial schematic and layout
    Organized schematic
    Rearranged power circuitry to make routing other components easier
    Finished routing board
    [Thing_Plus_ESP32_C6.brd, Thing_Plus_ESP32_C6.sch]
2023-06-28 Design review updates
    Add measures
    Add ordering instructions
    Add notes about jumpers
    Add voltage regulator parameters
    Rearrange LED section in schematic
    [Thing_Plus_ESP32_C6.brd, Thing_Plus_ESP32_C6.sch]
2023-06-29 Design review updates
    Add RGB label to NC pin
    Move CHG LED to make room for RGB label
    Optimize GND pours
    Add GND vias
    Fix acid traps
    [Thing_Plus_ESP32_C6.brd]
2023-06-29 Design review updates
    Add fiducials
    Add top mounting holes under ESP32-C6 antenna
    Move OSHW logo and make bigger
    Change RGB jumper to NO
    [Thing_Plus_ESP32_C6.brd, Thing_Plus_ESP32_C6.sch]
2023-06-29 Add power control to uSD card
    Also add 10uF cap for uSD card
    And add boot button text
    [Thing_Plus_ESP32_C6.brd, Thing_Plus_ESP32_C6.sch]
2023-06-29 Add silk lines between passive components
    [Thing_Plus_ESP32_C6.brd]
2023-06-29 Checklist updates
    Add version number to copper
    Fix dimension lines to be exactly on grid
    Add PROD_ID to ESP32-C6 narrow device
    Add layer numbers to copper
    Add silk labels to SD_P jumper
    [Thing_Plus_ESP32_C6.brd, Thing_Plus_ESP32_C6.sch]
2023-06-29 Add v01 panel files
    [Thing_Plus_ESP32_C6-Panel.GBL, Thing_Plus_ESP32_C6-Panel.GBO, Thing_Plus_ESP32_C6-Panel.GBP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]
2023-07-31 v10 updates
    Change pinout of GPIO 15-23 (SDIO pins have funky behavior when not configured)
    Connect fuel gauge alert pin
    Move SD power control to own circuit that creates VOUT net
    Change STAT LED to get powered from VOUT
    Change RGB jumper to NC
    [Thing_Plus_ESP32_C6.brd, Thing_Plus_ESP32_C6.sch]
2023-07-31 Bump version number to v10
    [Thing_Plus_ESP32_C6.brd, Thing_Plus_ESP32_C6.sch]
2023-08-01 Design review updates
    Change schematic frame to ledger
    Fix acid trap
    Approve DRC errors on jumpers
    [Thing_Plus_ESP32_C6.brd, Thing_Plus_ESP32_C6.sch]
2023-08-01 Add v10 panel files
    [Thing_Plus_ESP32_C6-Panel.GBL, Thing_Plus_ESP32_C6-Panel.GBP, Thing_Plus_ESP32_C6-Panel.GBS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]
2023-08-01 Change RGB jumper to NO
    Won't violate the form factor standard by default this time!
    Also update panel files
    [Thing_Plus_ESP32_C6-Panel.brd, Thing_Plus_ESP32_C6.brd, Thing_Plus_ESP32_C6.sch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]
2023-08-15 Fix schematic note about RGB jumper
    [Thing_Plus_ESP32_C6.sch]
2023-09-19 Change C6 to DNP
    Rise time was slow, causing chip to run bootloader instead of booting from flash
    [Thing_Plus_ESP32_C6-Panel.brd, Thing_Plus_ESP32_C6.brd, Thing_Plus_ESP32_C6.sch]
2024-01-17 Docs update
    Adding board files, common img & updating software sections.
2024-01-31 Docs Update
    Example code and software setup update. Adding RGB example and reworking boards package install instructions.
2024-02-06 Docs Review
    Final review updates. Switching to updated "Print View" option for single page.
2024-07-09 Espressif Boards Package Update
    Updating software setup & examples with espressif Arduino Boards v3 release.

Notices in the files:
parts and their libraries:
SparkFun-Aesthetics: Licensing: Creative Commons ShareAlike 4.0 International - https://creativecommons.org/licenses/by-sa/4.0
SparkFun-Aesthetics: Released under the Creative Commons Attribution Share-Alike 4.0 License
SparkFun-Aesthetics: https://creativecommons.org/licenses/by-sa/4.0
